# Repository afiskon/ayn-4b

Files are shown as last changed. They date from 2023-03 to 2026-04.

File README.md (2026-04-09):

# AYN/4B

Portable QRP CW Transceiver

* Covers 40, 30, 20 and 17 meters
* Classical single IF superheterodyne design
* Has just a few barely hearable (~S0) spurious signals
* Simple but effective AGC
* Supports RIT and XIT
* 10-30 WPM Elekey-B type keyer + straight key mode
* Keyer supports record and playback, programmable with paddles
* ~5W class D power amplifier
* Has a VCC indicator and a SWR meter
* PCB is designed to fit into Hammond 1590BB enclosure
* The project is 100% open-source

Links:
* Article (in Russian): https://eax.me/2023/2023-05-01-ayn-4b-transceiver.html
* Demo: https://www.youtube.com/watch?v=IM0qo4IA7QQ
* Fork by Kirill, R2AXZ with CMake support: https://github.com/r2axz/ayn-4b

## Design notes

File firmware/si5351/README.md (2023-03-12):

# stm32-si5351

HAL-based Si5351 driver for STM32.

Main respository: https://github.com/afiskon/stm32-si5351

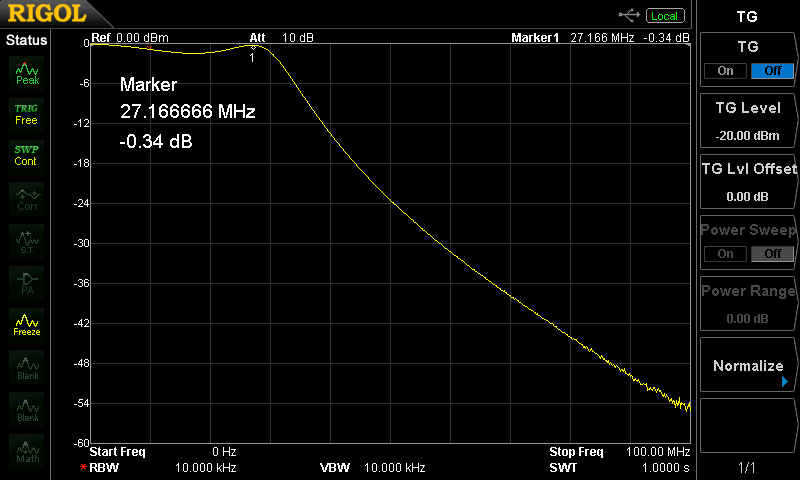
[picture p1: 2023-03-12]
images/lpfs/vfo-filter.png

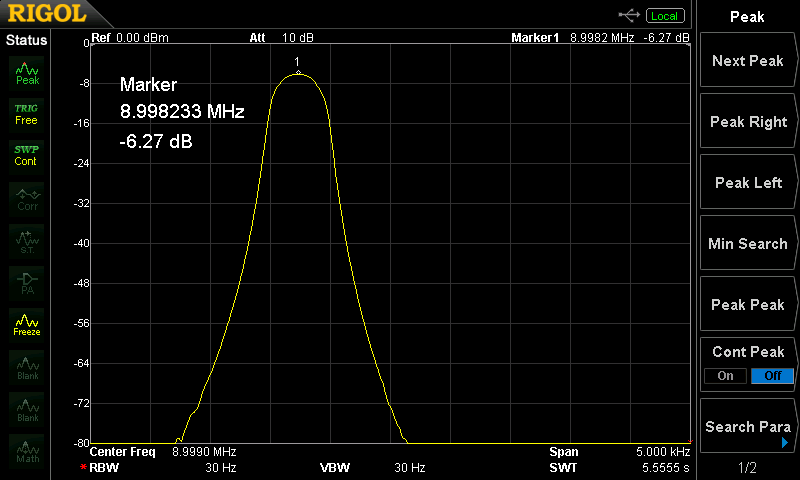
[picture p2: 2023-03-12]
images/xtal-filter/insertion-loss.png

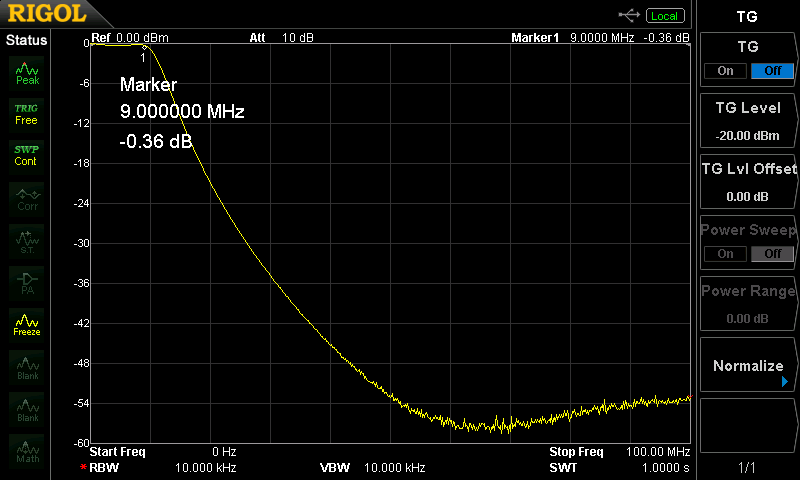
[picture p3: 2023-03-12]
images/lpfs/bfo-filter.png

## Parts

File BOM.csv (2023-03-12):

Reference | Quantity | Value | Footprint
C1 C93 C94 | 3 | 470p | Capacitor_SMD:C_0805_2012Metric_Pad1.15x1.40mm_HandSolder
C10 | 1 | 3.9p | Capacitor_SMD:C_0805_2012Metric_Pad1.15x1.40mm_HandSolder
C11 | 1 | 5.6p | Capacitor_SMD:C_0805_2012Metric_Pad1.15x1.40mm_HandSolder
C14 C95 C96 | 3 | 220p | Capacitor_SMD:C_0805_2012Metric_Pad1.15x1.40mm_HandSolder
C13 C15 C16 C17 | 4 | 330p | Capacitor_SMD:C_0805_2012Metric_Pad1.15x1.40mm_HandSolder
C19 | 1 | 33p | Capacitor_SMD:C_0805_2012Metric_Pad1.15x1.40mm_HandSolder
C3 C6 | 2 | 0.47u | Capacitor_SMD:C_0805_2012Metric_Pad1.15x1.40mm_HandSolder
C2 C4 C5 C7 C26 C27 C28 C29 C30 C31 C32 C34 C35 C36 C37 C38 C39 C40 C41 C42 C43 C45 C49 C50 C51 C53 C54 C55 C57 C81 C88 C89 C90 C91 C92 C97 C99 C102 C104 C105 | 40 | 0.1u | Capacitor_SMD:C_0805_2012Metric_Pad1.15x1.40mm_HandSolder
C46 C86 | 2 | 0.047u | Capacitor_SMD:C_0805_2012Metric_Pad1.15x1.40mm_HandSolder
C44 C47 C82 C83 C84 | 5 | 10u | Capacitor_SMD:CP_Elec_4x5.4
C48 | 1 | 2.2u | Capacitor_SMD:CP_Elec_4x5.4
C52 | 1 | 220u | Capacitor_SMD:CP_Elec_8x10.5
C60 C65 C70 C75 C80 C98 | 6 | 270p | Capacitor_SMD:C_0805_2012Metric_Pad1.15x1.40mm_HandSolder
C18 C20 C21 C22 C23 C24 C61 C64 C100 C101 | 10 | 150p | Capacitor_SMD:C_0805_2012Metric_Pad1.15x1.40mm_HandSolder
C62 C63 C67 C68 C72 C73 C77 C78 C103 | 9 | 1-30p | My_Library:C_Trim_THD_L7.0mm_W6.5mm_P5.00mm
C66 C69 | 2 | 100p | Capacitor_SMD:C_0805_2012Metric_Pad1.15x1.40mm_HandSolder
C71 C74 | 2 | 47p | Capacitor_SMD:C_0805_2012Metric_Pad1.15x1.40mm_HandSolder
C12 C25 C76 C79 | 4 | 68p | Capacitor_SMD:C_0805_2012Metric_Pad1.15x1.40mm_HandSolder
C8 | 1 | 15p | Capacitor_SMD:C_0805_2012Metric_Pad1.15x1.40mm_HandSolder
C33 C56 C58 C59 C85 | 5 | 0.01u | Capacitor_SMD:C_0805_2012Metric_Pad1.15x1.40mm_HandSolder
C87 | 1 | 22u | Capacitor_SMD:CP_Elec_5x5.4
C9 | 1 | 8p | Capacitor_SMD:C_0805_2012Metric_Pad1.15x1.40mm_HandSolder
D1 D2 D3 D6 D7 D8 D9 D10 D11 D12 D13 D15 D17 | 13 | 1N4148W | Diode_SMD:D_SOD-123
D14 | 1 | SS14 | Diode_SMD:D_SMA_Handsoldering
D16 | 1 | 1N4736A | Diode_THT:D_DO-41_SOD81_P2.54mm_Vertical_AnodeUp
D4 D5 | 2 | 1N34/D311 matched pair | Diode_THT:D_DO-41_SOD81_P2.54mm_Vertical_AnodeUp
K1 K2 K3 K4 K5 K6 K7 K8 K9 K10 K11 K12 | 12 | G6K-2F-Y (or: HFD4/12-S) | Relay_SMD:Relay_DPDT_Omron_G6K-2F-Y
Q1 Q2 Q5 Q6 Q8 Q9 Q10 Q11 Q13 Q14 Q15 Q16 Q17 Q18 | 14 | MMBT3904 | Package_TO_SOT_SMD:SOT-23
Q12 | 1 | BS170 | Package_TO_SOT_THT:TO-92_Inline
Q3 | 1 | MMBF170 | Package_TO_SOT_SMD:SOT-23
Q4 | 1 | MMBT3906 | Package_TO_SOT_SMD:SOT-23
Q7 | 1 | IRF510 | Package_TO_SOT_THT:TO-220-3_Vertical
R1 | 1 | 15K | Resistor_SMD:R_0805_2012Metric_Pad1.15x1.40mm_HandSolder
R11 | 1 | 220 | Resistor_SMD:R_0805_2012Metric_Pad1.15x1.40mm_HandSolder
R14 R21 R23 | 3 | 1.3K | Resistor_SMD:R_0805_2012Metric_Pad1.15x1.40mm_HandSolder
R15 R24 R26 | 3 | 68 | Resistor_SMD:R_0805_2012Metric_Pad1.15x1.40mm_HandSolder
R17 R28 R29 | 3 | 6.2 | Resistor_SMD:R_0805_2012Metric_Pad1.15x1.40mm_HandSolder
R2 R5 R6 R54 R66 R67 R68 R69 | 8 | 4.7K | Resistor_SMD:R_0805_2012Metric_Pad1.15x1.40mm_HandSolder
R3 | 1 | 2.7K | Resistor_SMD:R_0805_2012Metric_Pad1.15x1.40mm_HandSolder
R30 R31 | 2 | 150 | Resistor_SMD:R_0805_2012Metric_Pad1.15x1.40mm_HandSolder
R32 | 1 | 36 | Resistor_SMD:R_0805_2012Metric_Pad1.15x1.40mm_HandSolder
R33 R59 R60 R63 R64 | 5 | 100 | Resistor_SMD:R_0805_2012Metric_Pad1.15x1.40mm_HandSolder
R34 R53 | 2 | 2.2K | Resistor_SMD:R_0805_2012Metric_Pad1.15x1.40mm_HandSolder
R35 R40 R45 | 3 | 100K | Resistor_SMD:R_0805_2012Metric_Pad1.15x1.40mm_HandSolder
R13 R20 R22 R36 | 4 | 3.3K | Resistor_SMD:R_0805_2012Metric_Pad1.15x1.40mm_HandSolder
R37 | 1 | 47K | Resistor_SMD:R_0805_2012Metric_Pad1.15x1.40mm_HandSolder
R10 R16 R25 R27 R38 R48 R56 R57 | 8 | 1K | Resistor_SMD:R_0805_2012Metric_Pad1.15x1.40mm_HandSolder
R39 | 1 | 51 | Resistor_SMD:R_0805_2012Metric_Pad1.15x1.40mm_HandSolder
R4 R9 R41 R42 R43 R44 | 6 | 1.8K | Resistor_SMD:R_0805_2012Metric_Pad1.15x1.40mm_HandSolder
R12 R18 R19 R46 R49 | 5 | 22 | Resistor_SMD:R_0805_2012Metric_Pad1.15x1.40mm_HandSolder
R50 | 1 | 10 | Resistor_SMD:R_0805_2012Metric_Pad1.15x1.40mm_HandSolder
R51 | 1 | 1Meg | Resistor_SMD:R_0805_2012Metric_Pad1.15x1.40mm_HandSolder
R52 R61 R65 | 3 | 680 | Resistor_SMD:R_0805_2012Metric_Pad1.15x1.40mm_HandSolder
R47 R55 | 2 | 10K | Resistor_SMD:R_0805_2012Metric_Pad1.15x1.40mm_HandSolder
R58 R62 | 2 | 300 | Resistor_SMD:R_0805_2012Metric_Pad1.15x1.40mm_HandSolder
RV1 RV2 RV3 RV4 | 4 | 10K | Potentiometer_THT:Potentiometer_Bourns_3296W_Vertical
U1 | 1 | L7805 | Package_TO_SOT_THT:TO-220-3_Vertical
U10 | 1 | LM386 | Package_SO:SO-8_5.3x6.2mm_P1.27mm
U11 | 1 | L7805 | Package_TO_SOT_SMD:TO-263-2
U2 | 1 | 24LC64 | Package_SO:SO-8_5.3x6.2mm_P1.27mm
U3 U4 | 2 | ADE-6 (or: ADE-1/ADE-1L/ADE-2) | RF_Mini-Circuits:Mini-Circuits_CD542_LandPatternPL-052
U5 | 1 | NE5532 | Package_SO:SOIC-8_5.23x5.23mm_P1.27mm
Y1 Y2 Y3 Y4 Y5 Y6 | 6 | 9 Mhz, see notes
T1 T2 T3 T12 L9 | 5 | FT37-43
T4 T5 T6 T7 T8 T9 T10 T11 L3 L4 L5 L6 L7 L8 L10 L11 | 16 | T37-6
J8 J9 J11 J12 | 1 | BN61-202
L1 L2 | 2 | 1000u
L12 | 1 | 18u
J2 | 1 | Si5351 Module
J3 J4 | 1 | Blue Pill

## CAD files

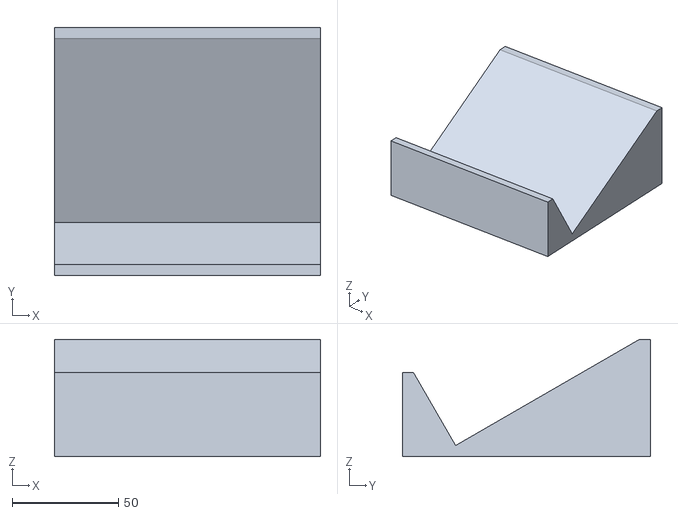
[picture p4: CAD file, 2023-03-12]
stl-files/desktop-stand.stl
125.0 x 116.6 x 55.0

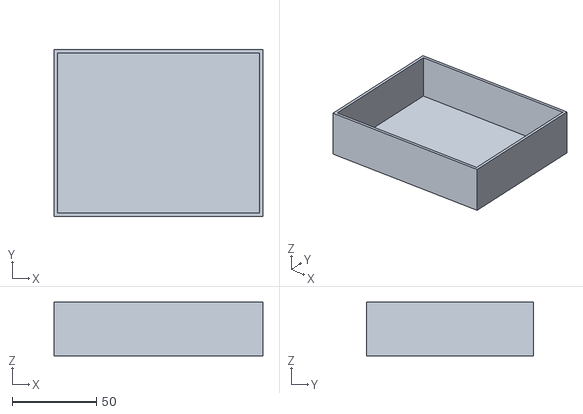
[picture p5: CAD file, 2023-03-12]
stl-files/dust-cover.stl
124.0 x 99.0 x 32.0

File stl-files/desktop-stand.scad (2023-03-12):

X = 125;
Y = 100;
Z = 40;
T = 5;
A = 30;
eps = 0.01;

by = T*2 + Y*sin(90-A) + Z*sin(A);
bx = X;
bz = T + Y*sin(A);


difference(){
    cube([bx, by, bz], center = true);

    translate([0,0, Z/2])
        rotate([A, 0, 0])
            cube([X+eps, Y, Z], center = true);
    
    translate([0, -Z, Z*0.8])
        cube([X+eps, Z, Z], center = true);
}

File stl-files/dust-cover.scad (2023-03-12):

T = 2;
X = 120;
Y = 95;
Z = 30;
eps = 0.01;

difference() {
    cube([X+2*T, Y+2*T, Z+T], center = true);
    translate([0, 0, T/2 + eps])
        cube([X, Y, Z], center = true);
}

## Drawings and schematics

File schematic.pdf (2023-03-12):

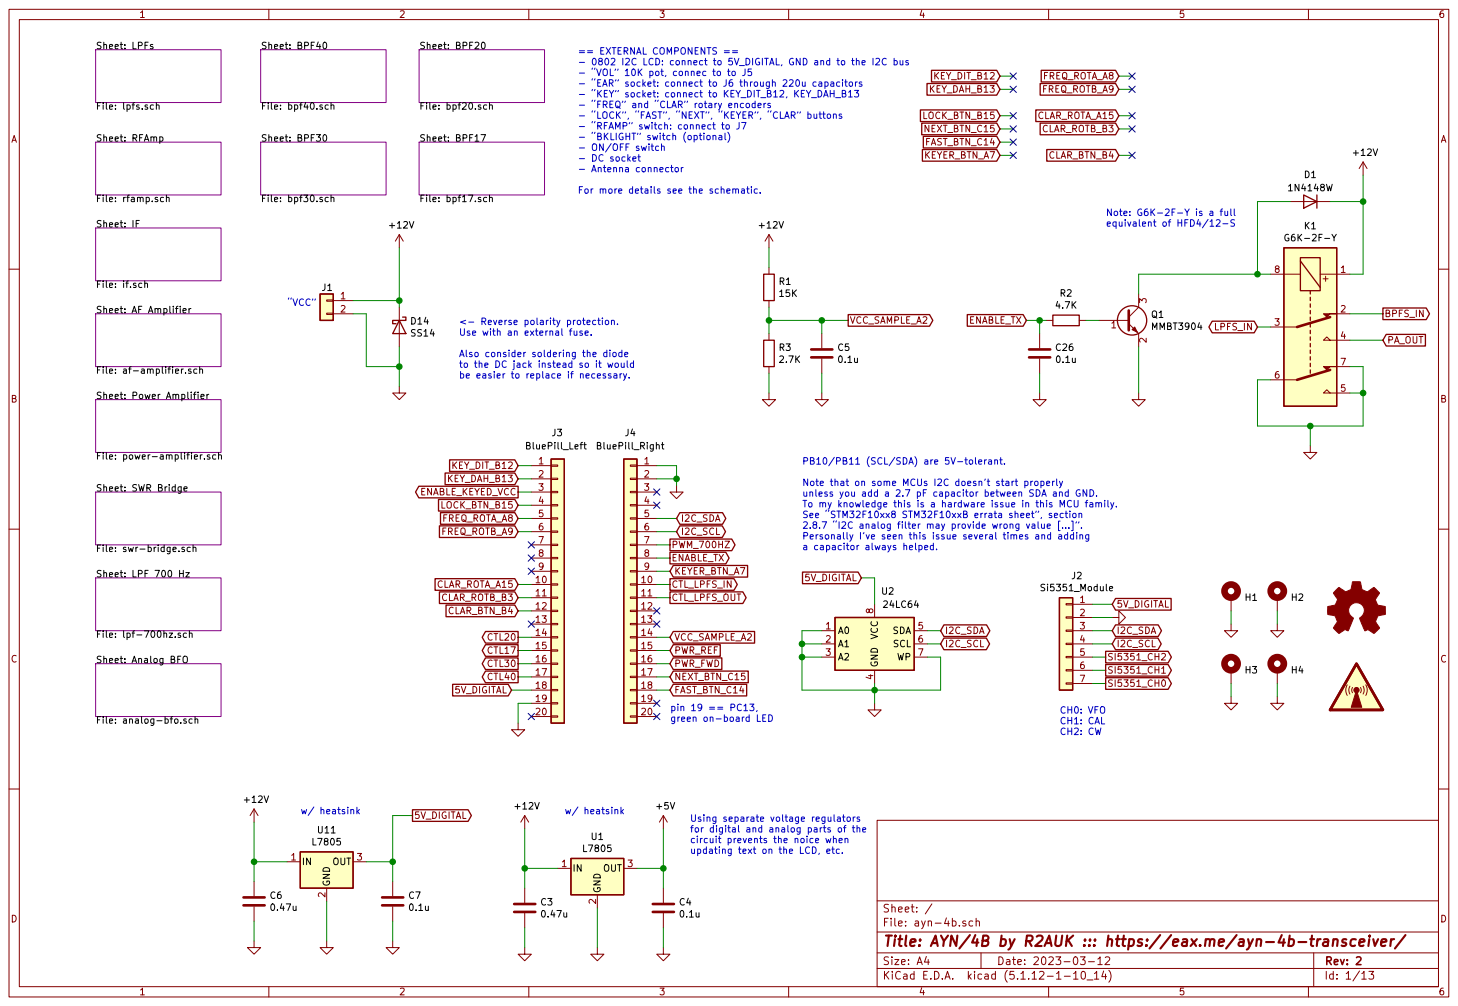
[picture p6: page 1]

- DC socket - Antenna connector For more details see the schematic. pin 19 == PC13,

File: if.sch Sheet: RFAmp
File: analog-bfo.sch Sheet: LPF 700 Hz File: lpf-700hz.sch Sheet: IF

== EXTERNAL COMPONENTS ==
- 0802 I2C LCD: connect to 5V_DIGITAL, GND and to the I2C bus
- VOL 10K pot, connec to to J5
- EAR socket: connect to J6 through 220u capacitors
- KEY socket: connect to KEY_DIT_B12, KEY_DAH_B13
- FREQ and CLAR rotary encoders
- LOCK, FAST, NEXT, KEYER, CLAR buttons
- RFAMP switch: connect to J7
- BKLIGHT switch (optional)
- ON/OFF switch

<- Reverse polarity protection. Use with an external fuse. Also consider soldering the diode

to the DC jack instead so it would
be easier to replace if necessary.

File: af-amplifier.sch

File: power-amplifier.sch

Note that on some MCUs I2C doesnt start properly
unless you add a 2.7 pF capacitor between SDA and GND.
To my knowledge this is a hardware issue in this MCU family. See STM32F10xx8 STM32F10xxB errata sheet, section

2.8.7 I2C analog filter may provide wrong value [].
Personally Ive seen this issue several times and adding
a capacitor always helped.

File: swr-bridge.sch

4 SDA 5 SCL 6 WP 7 VCC

Using separate voltage regulators
for digital and analog parts of the
circuit prevents the noice when
updating text on the LCD, etc.

File: ayn-4b.sch Sheet: /
Id: 1/13 Title: AYN/4B by R2AUK ::: https://eax.me/ayn-4b-transceiver/

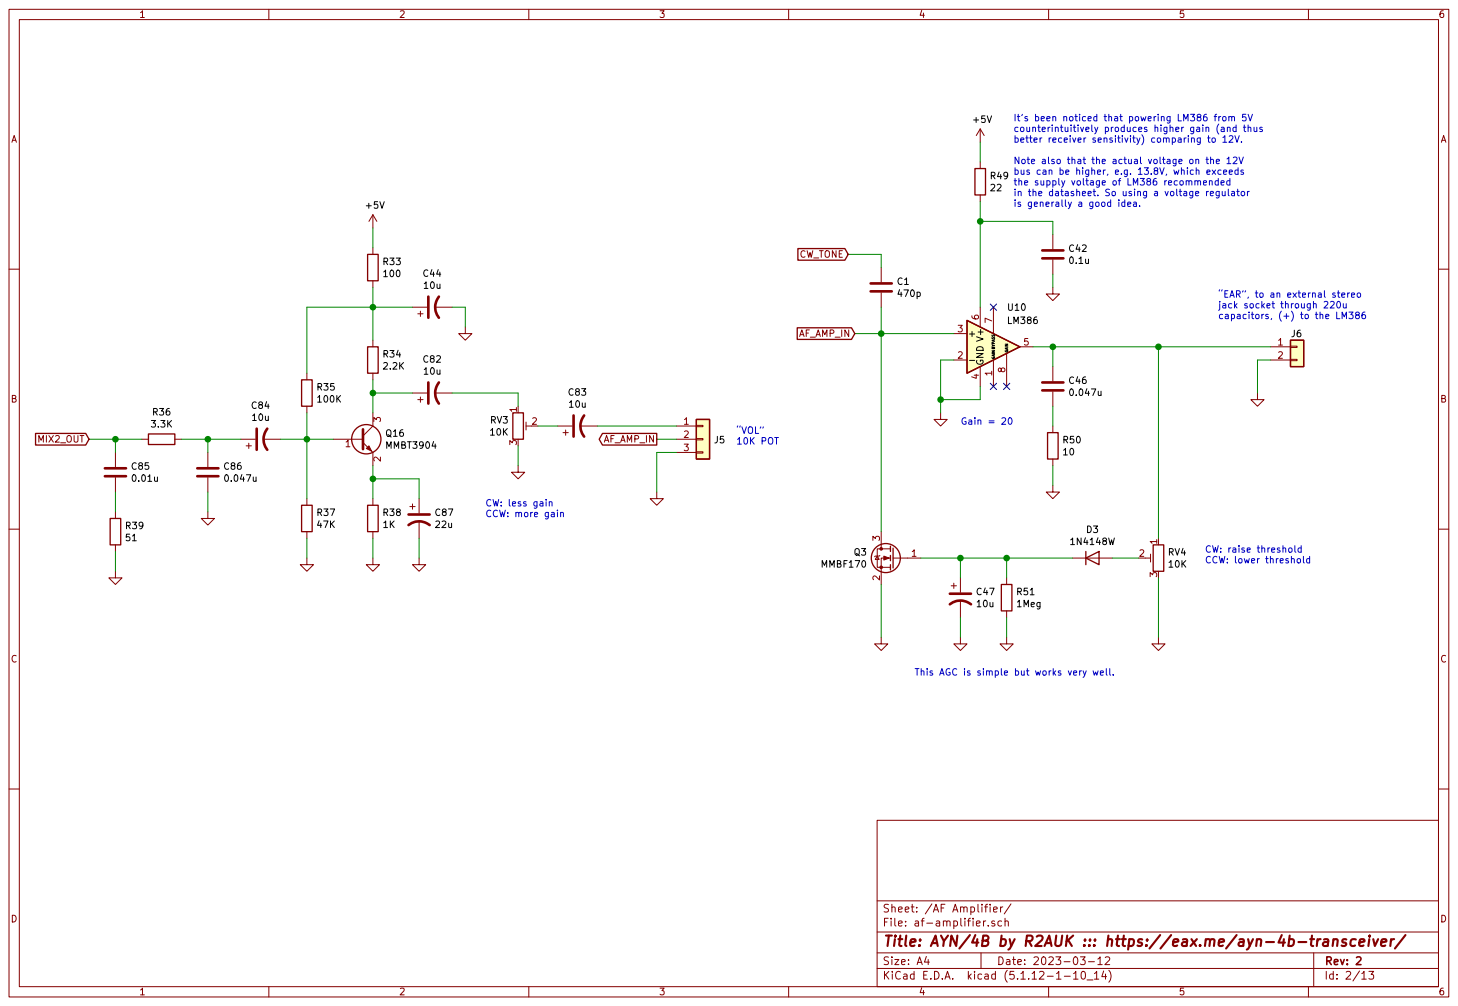
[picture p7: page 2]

Its been noticed that powering LM386 from 5V
counterintuitively produces higher gain (and thus
better receiver sensitivity) comparing to 12V.

Note also that the actual voltage on the 12V
bus can be higher, e.g. 13.8V, which exceeds
the supply voltage of LM386 recommended
in the datasheet. So using a voltage regulator

This AGC is simple but works very well. Gain = 20

Sheet: /AF Amplifier/
File: af-amplifier.sch
Id: 2/13 Title: AYN/4B by R2AUK ::: https://eax.me/ayn-4b-transceiver/

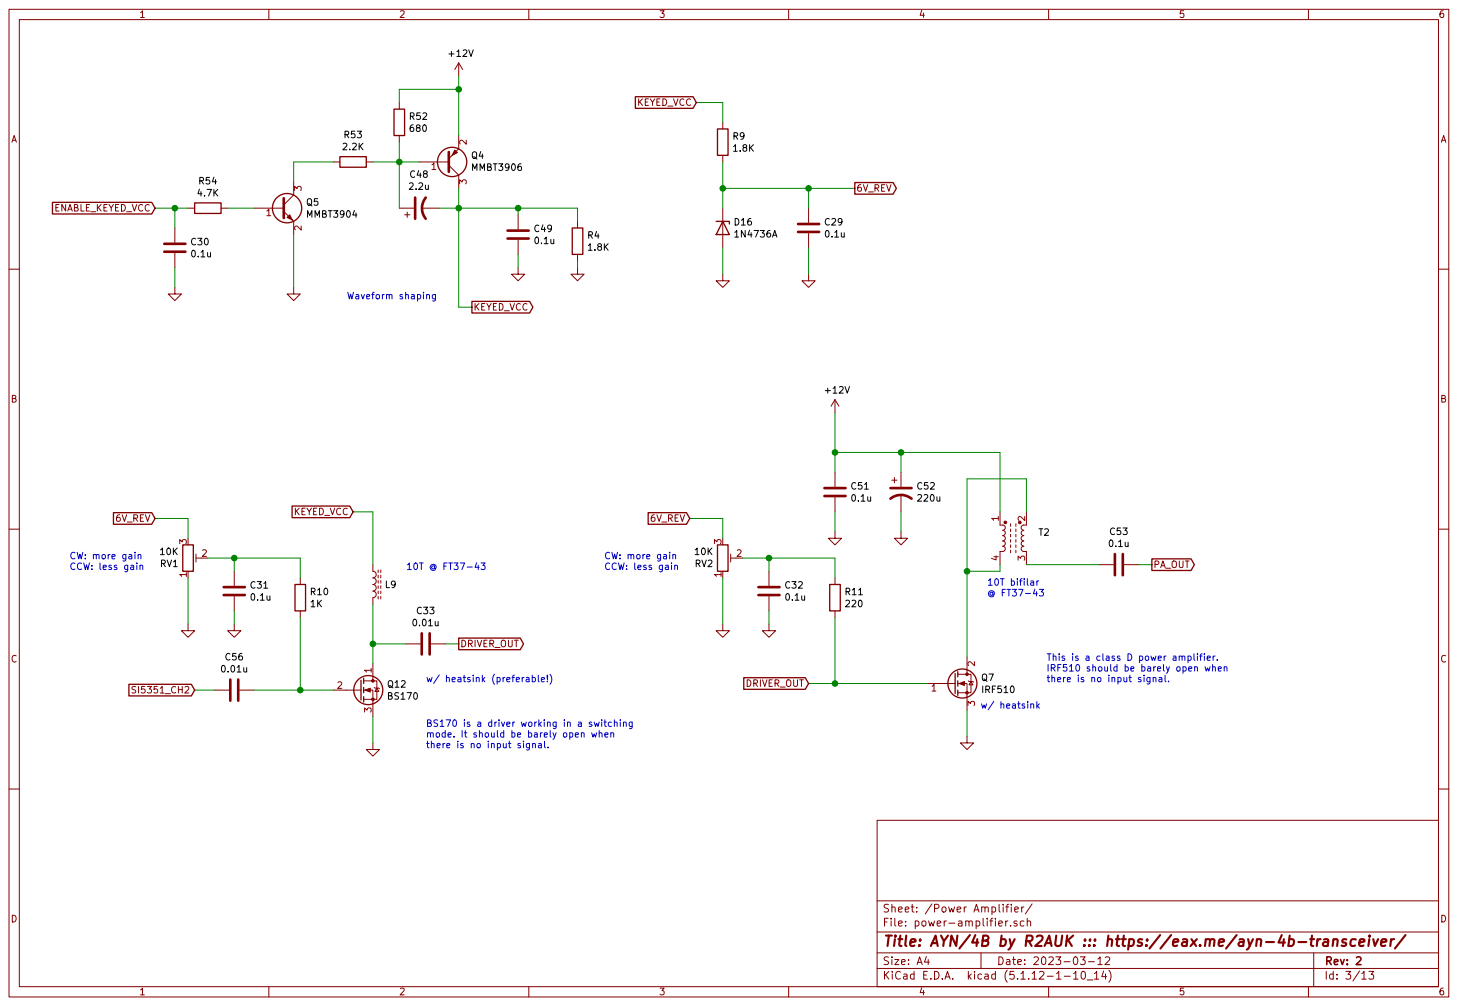
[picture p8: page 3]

IRF510 should be barely open when
there is no input signal.

BS170 is a driver working in a switching
mode. It should be barely open when

File: power-amplifier.sch
Id: 3/13 Title: AYN/4B by R2AUK ::: https://eax.me/ayn-4b-transceiver/

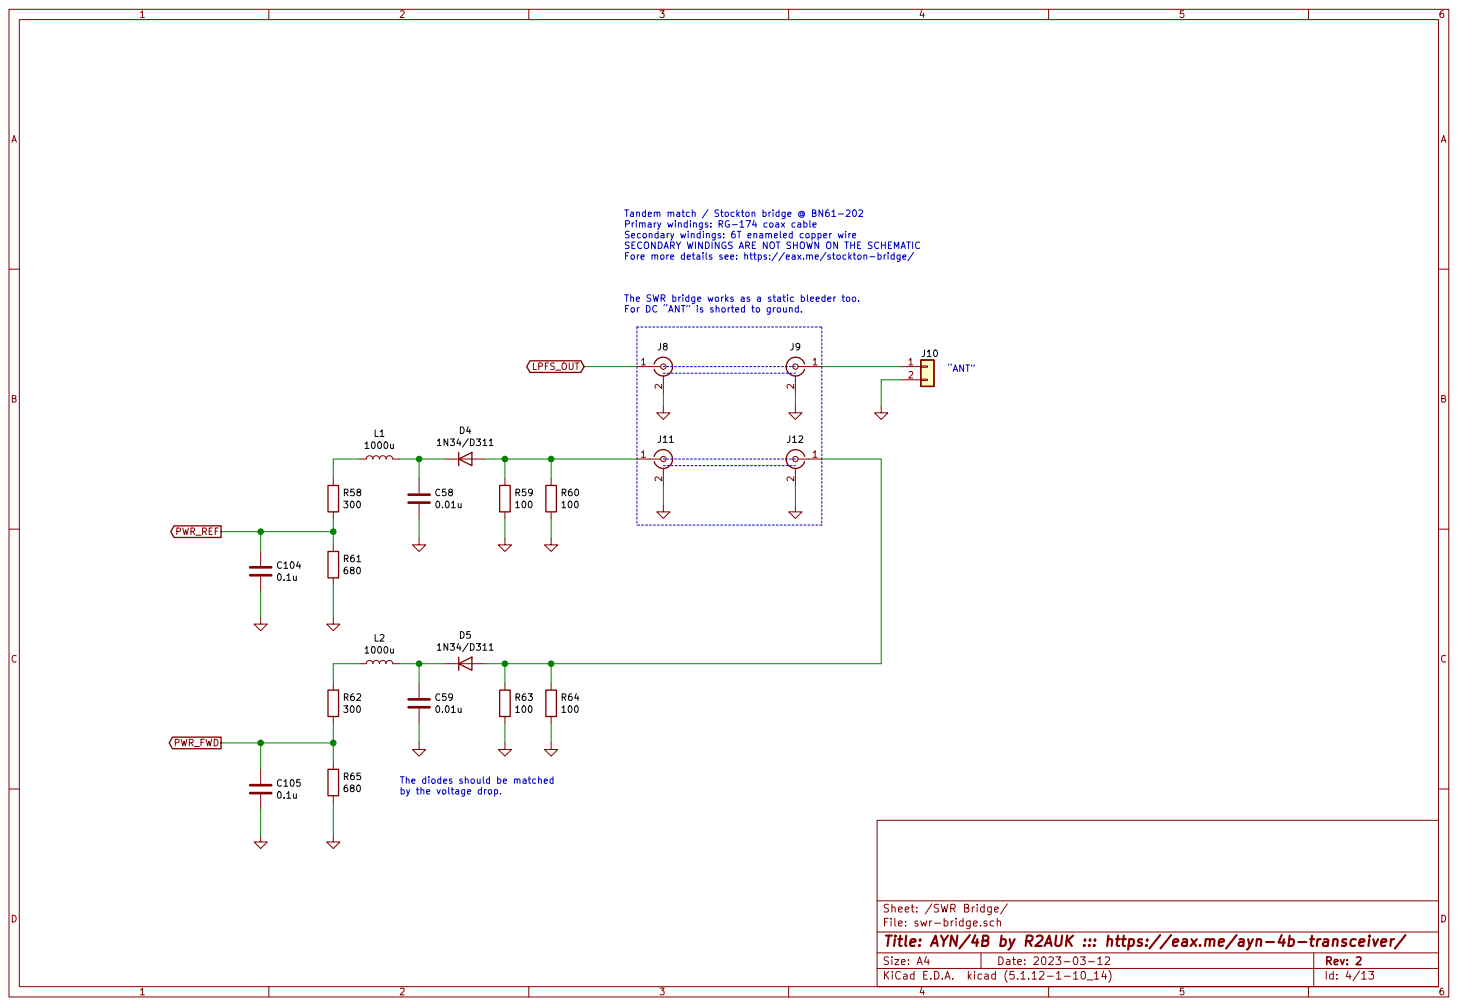
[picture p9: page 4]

Tandem match / Stockton bridge @ BN61-202
Primary windings: RG-174 coax cable
Secondary windings: 6T enameled copper wire SECONDARY WINDINGS ARE NOT SHOWN ON THE SCHEMATIC

Fore more details see: https://eax.me/stockton-bridge/

The SWR bridge works as a static bleeder too.

For DC ANT is shorted to ground. The diodes should be matched

Sheet: /SWR Bridge/
File: swr-bridge.sch
Id: 4/13 Title: AYN/4B by R2AUK ::: https://eax.me/ayn-4b-transceiver/

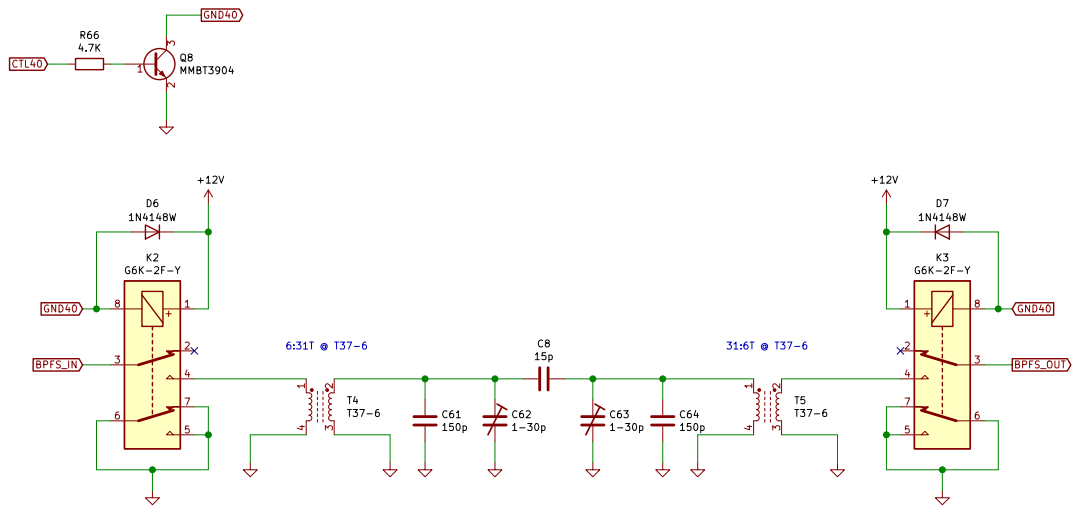
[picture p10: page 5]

Id: 5/13 Title: AYN/4B by R2AUK ::: https://eax.me/ayn-4b-transceiver/

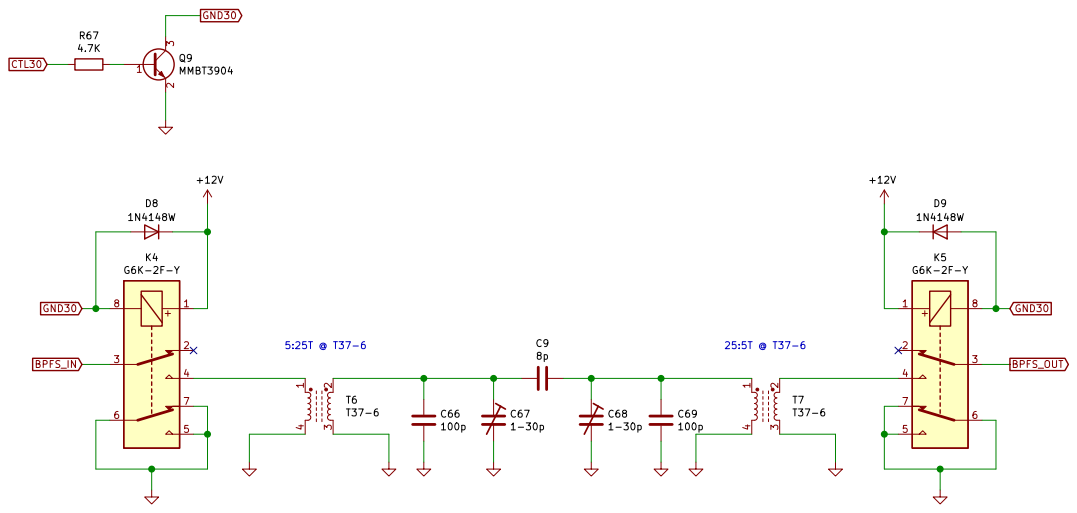
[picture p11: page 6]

Id: 6/13 Title: AYN/4B by R2AUK ::: https://eax.me/ayn-4b-transceiver/

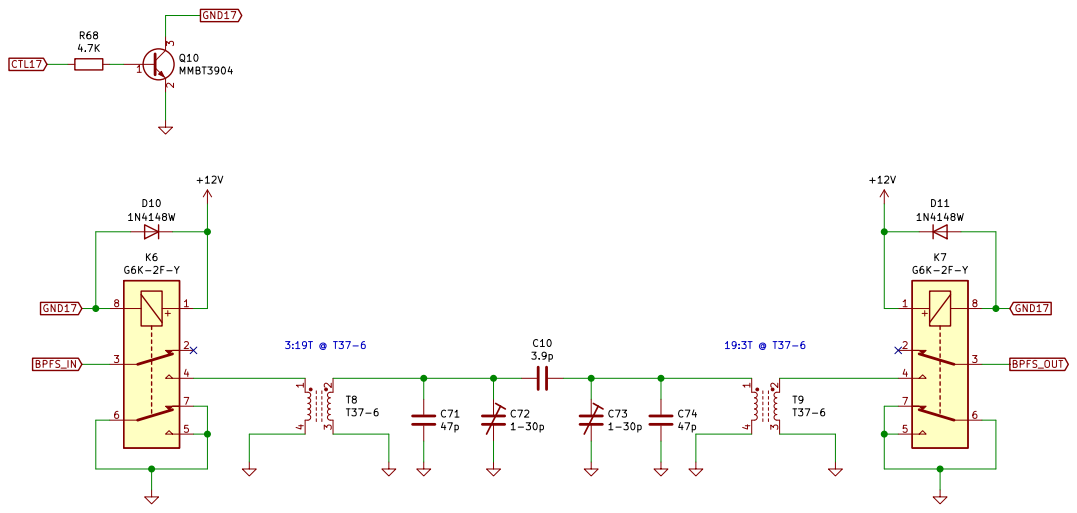
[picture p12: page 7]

Id: 7/13 Title: AYN/4B by R2AUK ::: https://eax.me/ayn-4b-transceiver/

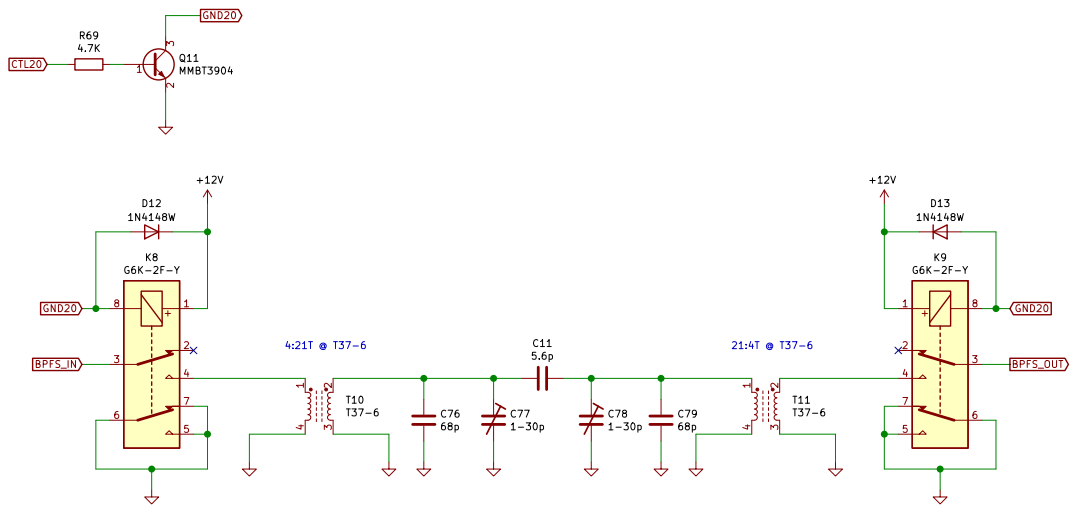
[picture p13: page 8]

Id: 8/13 Title: AYN/4B by R2AUK ::: https://eax.me/ayn-4b-transceiver/

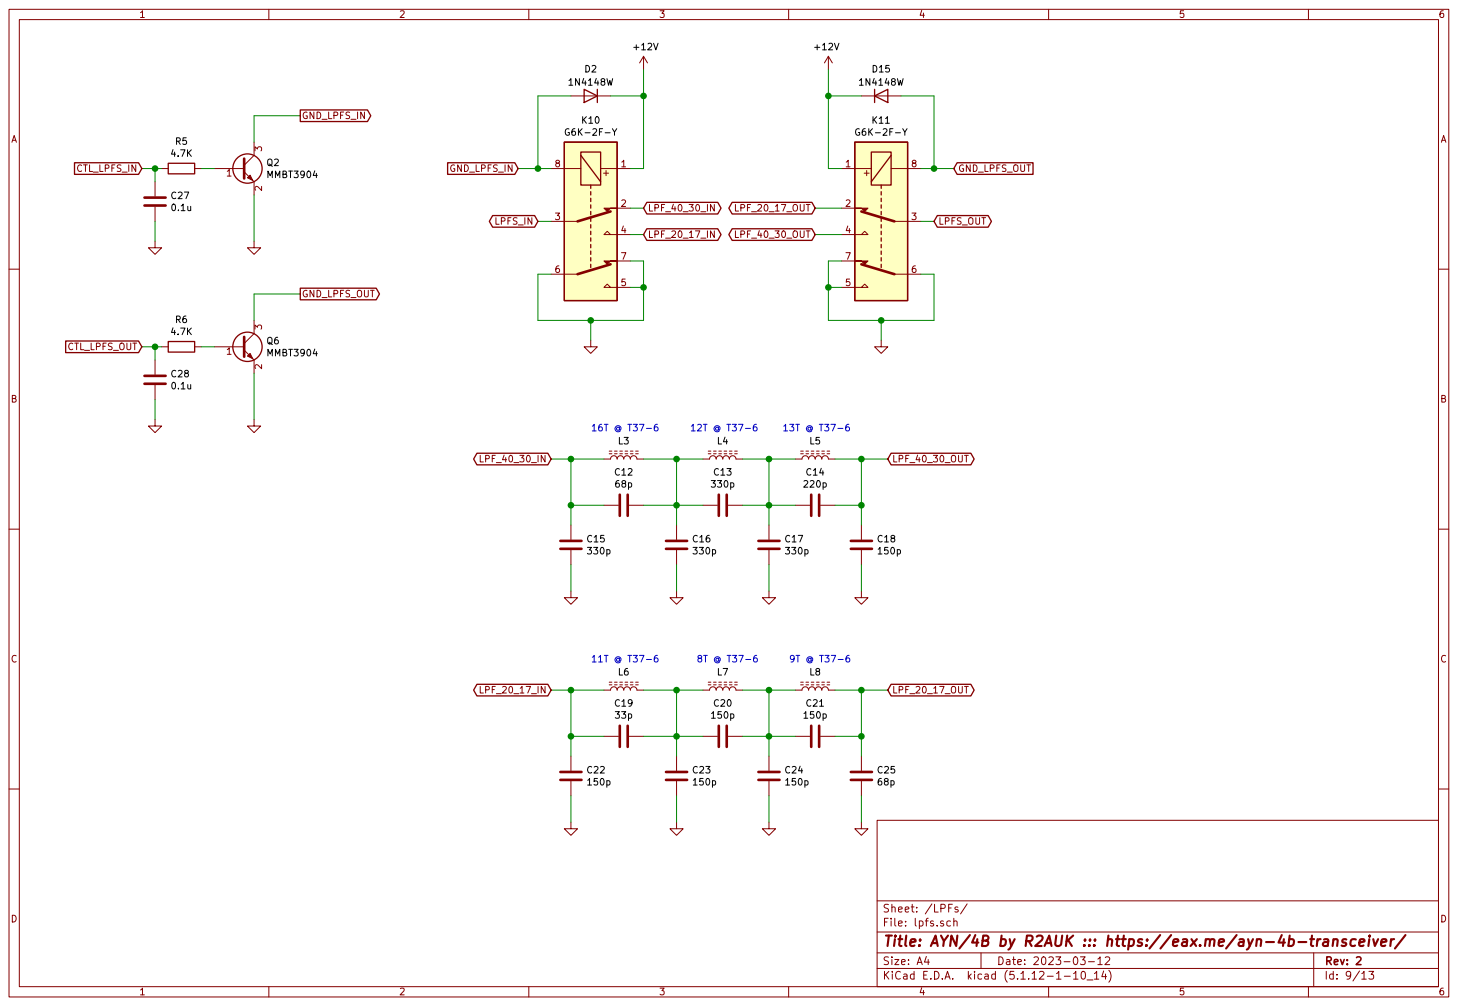
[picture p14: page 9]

File: lpfs.sch Sheet: /LPFs/
Id: 9/13 Title: AYN/4B by R2AUK ::: https://eax.me/ayn-4b-transceiver/

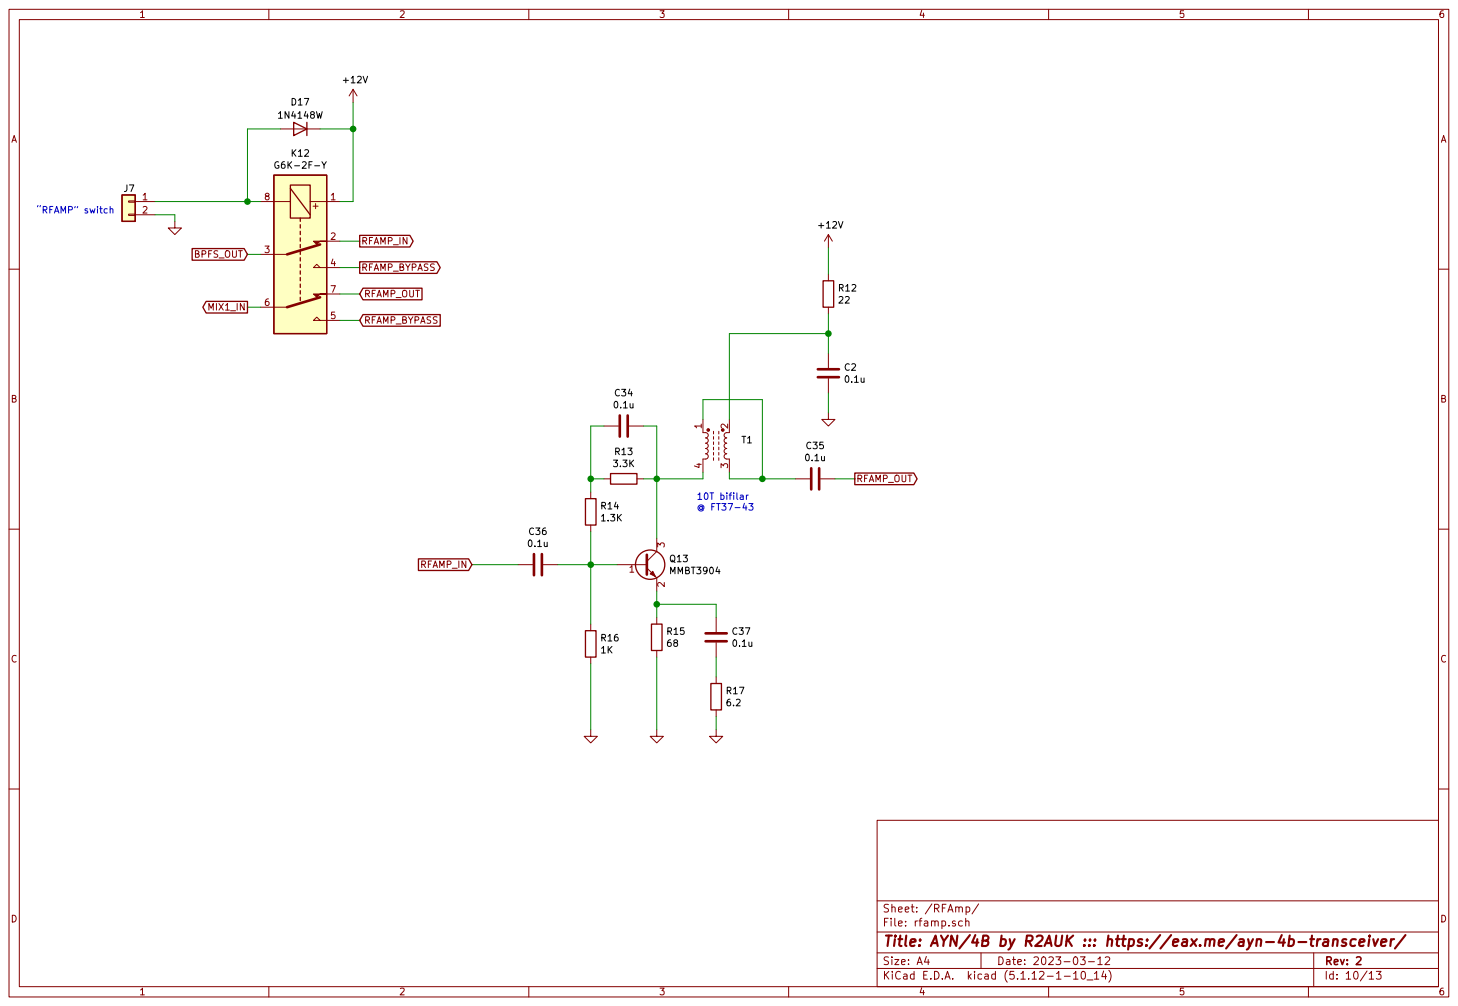
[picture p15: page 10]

Sheet: /RFAmp/
File: rfamp.sch
Id: 10/13 Title: AYN/4B by R2AUK ::: https://eax.me/ayn-4b-transceiver/

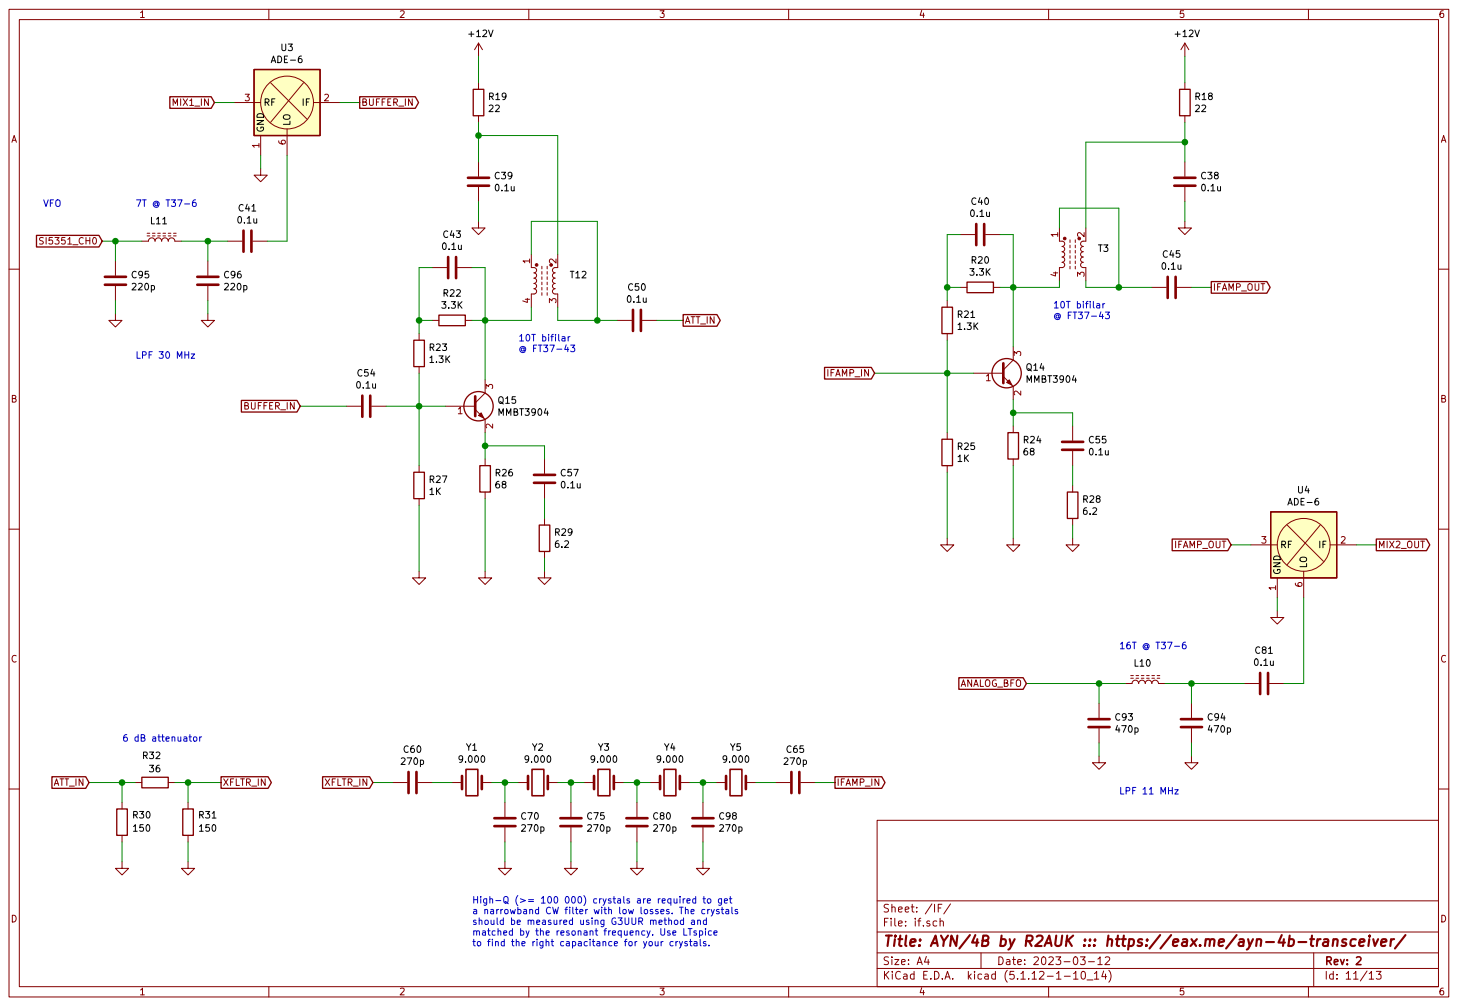
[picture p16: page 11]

Id: 11/13 Title: AYN/4B by R2AUK ::: https://eax.me/ayn-4b-transceiver/ File: if.sch Sheet: /IF/ GND

16T @ T37-6 High-Q (>= 100 000) crystals are required to get

a narrowband CW filter with low losses. The crystals
should be measured using G3UUR method and
matched by the resonant frequency. Use LTspice

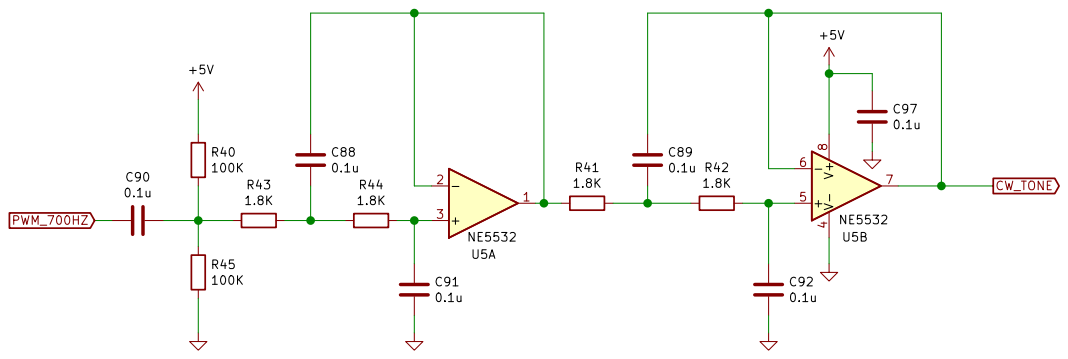
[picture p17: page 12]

File: lpf-700hz.sch Sheet: /LPF 700 Hz/
Id: 12/13 Title: AYN/4B by R2AUK ::: https://eax.me/ayn-4b-transceiver/


The secret of a superheterodyne receiver free of spurious
signals is a clean BFO. The signal of Si5351 is way too dirty
and cant be used as a BFO. Trust me, Ive tried many times.

The oscillator should be tuned to: (crystal filter center frequency) - 700 Hz

Example: Filter CF = 8.998.280 Hz Osc. Freq = 8.997.580 Hz

The expected output power to 50 Ohms is about
4 dBm on the main frequency (probably, mismatched).

This is not exactly 7 dBm typically required for a double
balanced diode ring mixer, but quite enought for ADE-6, see the datasheet. Some experimentation may be required.
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


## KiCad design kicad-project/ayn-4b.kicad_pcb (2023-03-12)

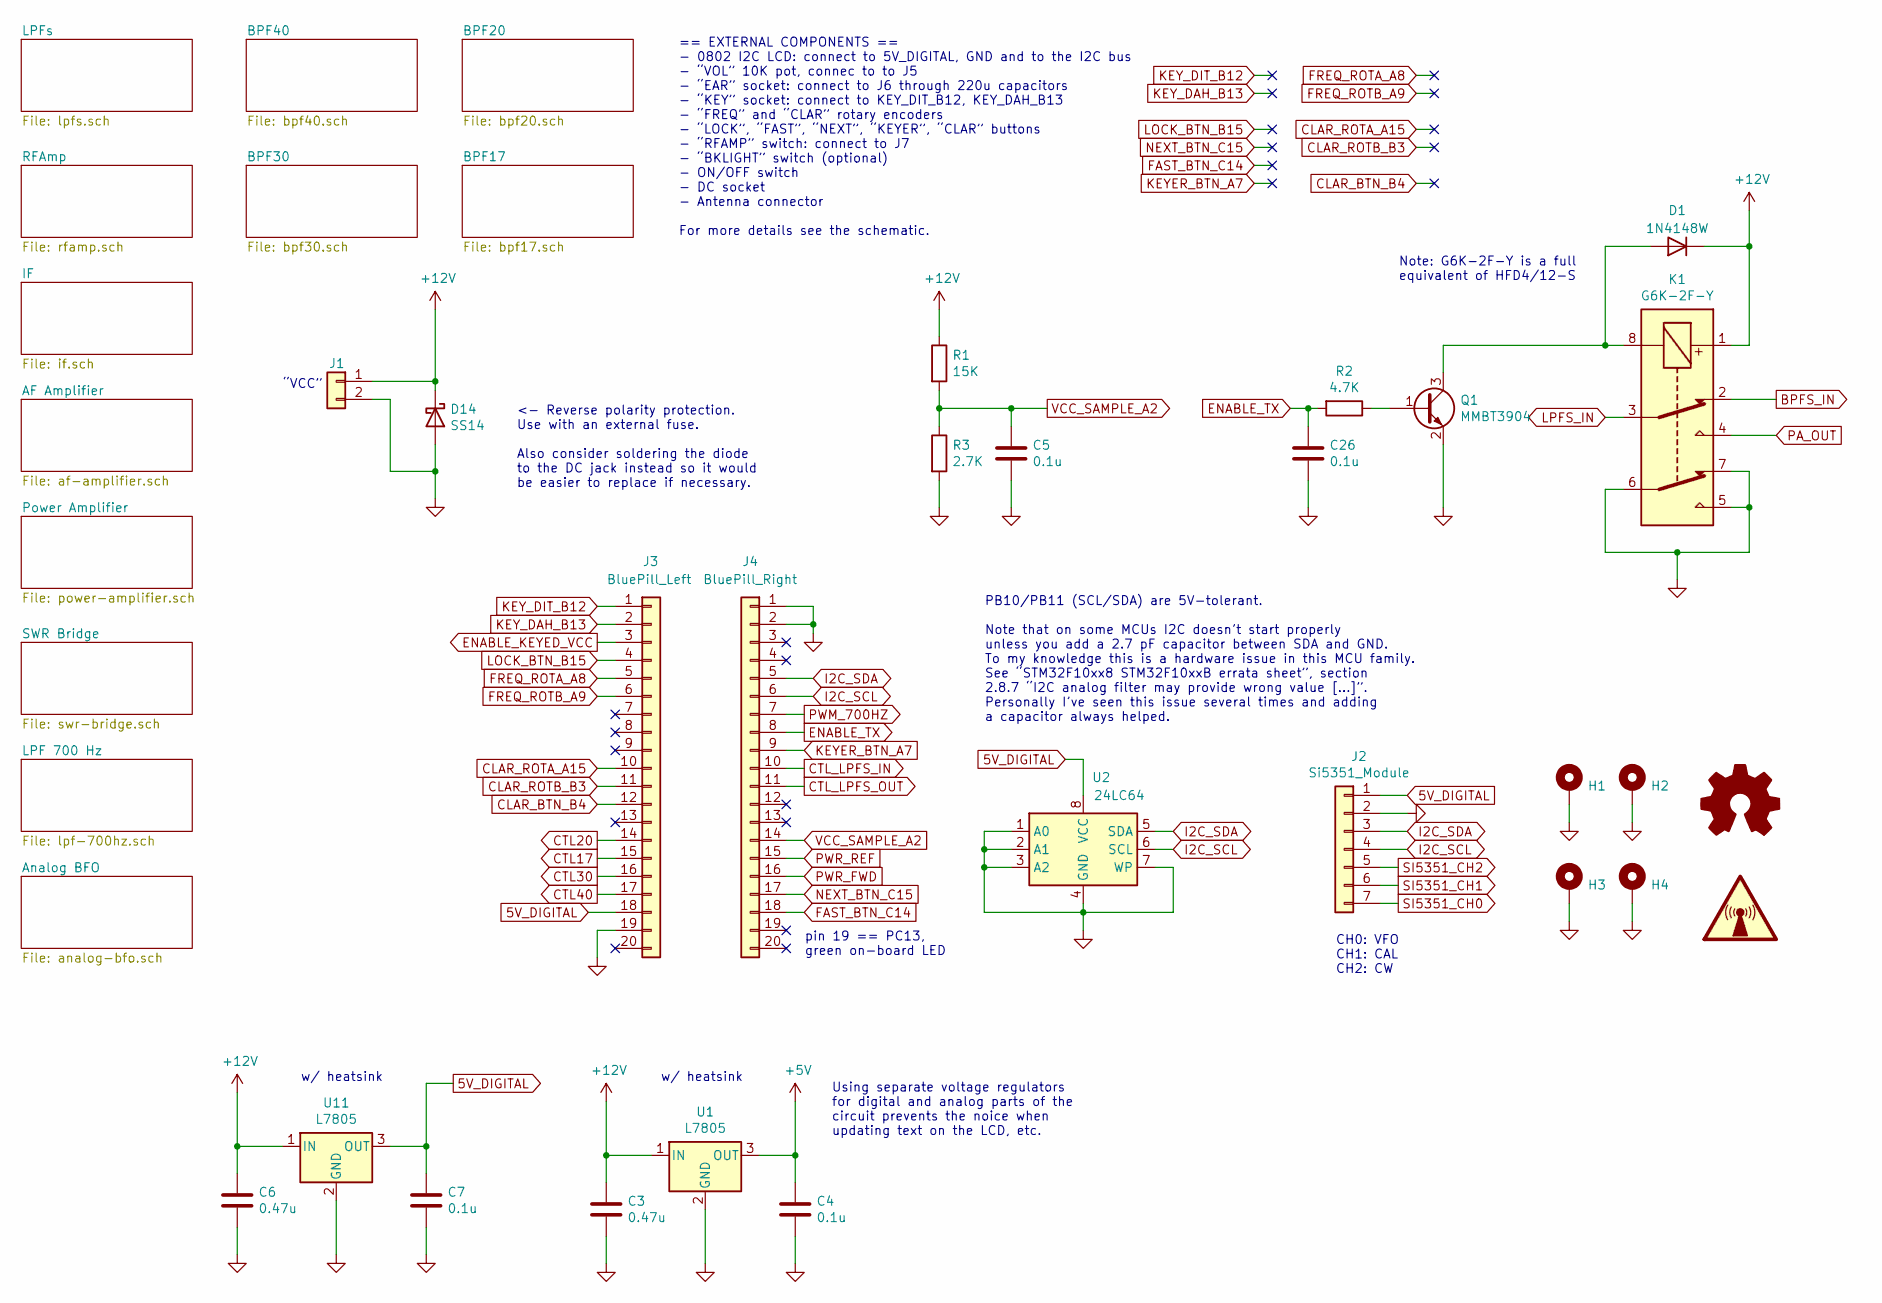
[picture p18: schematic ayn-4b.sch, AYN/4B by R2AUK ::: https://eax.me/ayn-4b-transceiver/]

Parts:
C3, C6: 0.47u; C_0805_2012Metric_Pad1.15x1.40mm_HandSolder
C4, C5, C7, C26: 0.1u; C_0805_2012Metric_Pad1.15x1.40mm_HandSolder
D1: 1N4148W; D_SOD-123
D14: SS14; D_SMA_Handsoldering
H1, H2, H3, H4: MountingHole_Pad; MountingHole_M3_Pad_Large
J1: Conn_01x02; PinSocket_1x02_P2.54mm_Vertical
J2: Si5351_Module; PinSocket_1x07_P2.54mm_Vertical
J3: BluePill_Left; PinSocket_1x20_P2.54mm_Vertical
J4: BluePill_Right; PinSocket_1x20_P2.54mm_Vertical
K1: G6K-2F-Y; Relay_DPDT_Omron_G6K-2F-Y
Q1: MMBT3904; SOT-23
R1: 15K; R_0805_2012Metric_Pad1.15x1.40mm_HandSolder
R2: 4.7K; R_0805_2012Metric_Pad1.15x1.40mm_HandSolder
R3: 2.7K; R_0805_2012Metric_Pad1.15x1.40mm_HandSolder
SYM1: Logo_Open_Hardware_Small; OSHW-Logo2_14.6x12mm_SilkScreen
SYM2: SYM_Radio_Waves_Large; KiCad-Logo_5mm_SilkScreen
U1: L7805; TO-220-3_Vertical
U2: 24LC64; SO-8_5.3x6.2mm_P1.27mm
U11: L7805; TO-263-2

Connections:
5V_DIGITAL: C7.1, J2.1, J3.18, U2.8 (VCC), U11.3 (OUT)
+5V: C4.1, U1.3 (OUT); also elsewhere on the board
+12V: C3.1, C6.1, D1.1 (K), D14.1 (K), J1.1, K1.1, R1.1, U1.1 (IN), U11.1 (IN); also elsewhere on the board
BPFS_IN: K1.2; also elsewhere on the board
CLAR_BTN_B4: J3.12
CLAR_ROTA_A15: J3.10
CLAR_ROTB_B3: J3.11
CTL17: J3.15; also elsewhere on the board
CTL20: J3.14; also elsewhere on the board
CTL30: J3.16; also elsewhere on the board
CTL40: J3.17; also elsewhere on the board
CTL_LPFS_IN: J4.10; also elsewhere on the board
CTL_LPFS_OUT: J4.11; also elsewhere on the board
ENABLE_KEYED_VCC: J3.3; also elsewhere on the board
ENABLE_TX: C26.1, J4.8, R2.2
FAST_BTN_C14: J4.18
FREQ_ROTA_A8: J3.5
FREQ_ROTB_A9: J3.6
GND: C3.2, C4.2, C5.2, C6.2, C7.2, C26.2, D14.2 (A), H1.1, H2.1, H3.1, H4.1, J1.2, J2.2, J3.19, J4.1, J4.2, K1.5, K1.6, K1.7, Q1.2 (E), R3.2, U1.2 (GND), U2.1 (A0), U2.2 (A1), U2.3 (A2), U2.4 (GND), U2.7 (WP), U11.2 (GND); also elsewhere on the board
I2C_SCL: J2.4, J4.6, U2.6 (SCL)
I2C_SDA: J2.3, J4.5, U2.5 (SDA)
KEYER_BTN_A7: J4.9
KEY_DAH_B13: J3.2
KEY_DIT_B12: J3.1
LOCK_BTN_B15: J3.4
LPFS_IN: K1.3; also elsewhere on the board
NEXT_BTN_C15: J4.17
unnamed: D1.2 (A), K1.8, Q1.3 (C)
unnamed: Q1.1 (B), R2.1
PA_OUT: K1.4; also elsewhere on the board
PWM_700HZ: J4.7; also elsewhere on the board
PWR_FWD: J4.16; also elsewhere on the board
PWR_REF: J4.15; also elsewhere on the board
SI5351_CH0: J2.7; also elsewhere on the board
SI5351_CH1: J2.6
SI5351_CH2: J2.5; also elsewhere on the board
VCC_SAMPLE_A2: C5.1, J4.14, R1.2, R3.1

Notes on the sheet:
CH0: VFO CH1: CAL CH2: CW
== EXTERNAL COMPONENTS == - 0802 I2C LCD: connect to 5V_DIGITAL, GND and to the I2C bus - “VOL” 10K pot, connec to to J5 - “EAR” socket: connect to J6 through 220u capacitors - “KEY” socket: connect to KEY_DIT_B12, KEY_DAH_B13 - “FREQ” and “CLAR” rotary encoders - “LOCK”, “FAST”, “NEXT”, “KEYER”, “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
w/ heatsink
Note: G6K-2F-Y is a full equivalent of HFD4/12-S
<- Reverse polarity protection. Use with an external fuse. Also consider soldering the diode to the DC jack instead so it would be easier to replace if necessary.
Using separate voltage regulators for digital and analog parts of the circuit prevents the noice when updating text on the LCD, etc.
“VCC”
PB10/PB11 (SCL/SDA) are 5V-tolerant. Note that on some MCUs I2C doesn’t start properly unless you add a 2.7 pF capacitor between SDA and GND. To my knowledge this is a hardware issue in this MCU family. See “STM32F10xx8 STM32F10xxB errata sheet”, section 2.8.7 “I2C analog filter may provide wrong v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
pin 19 == PC13, green on-board LED

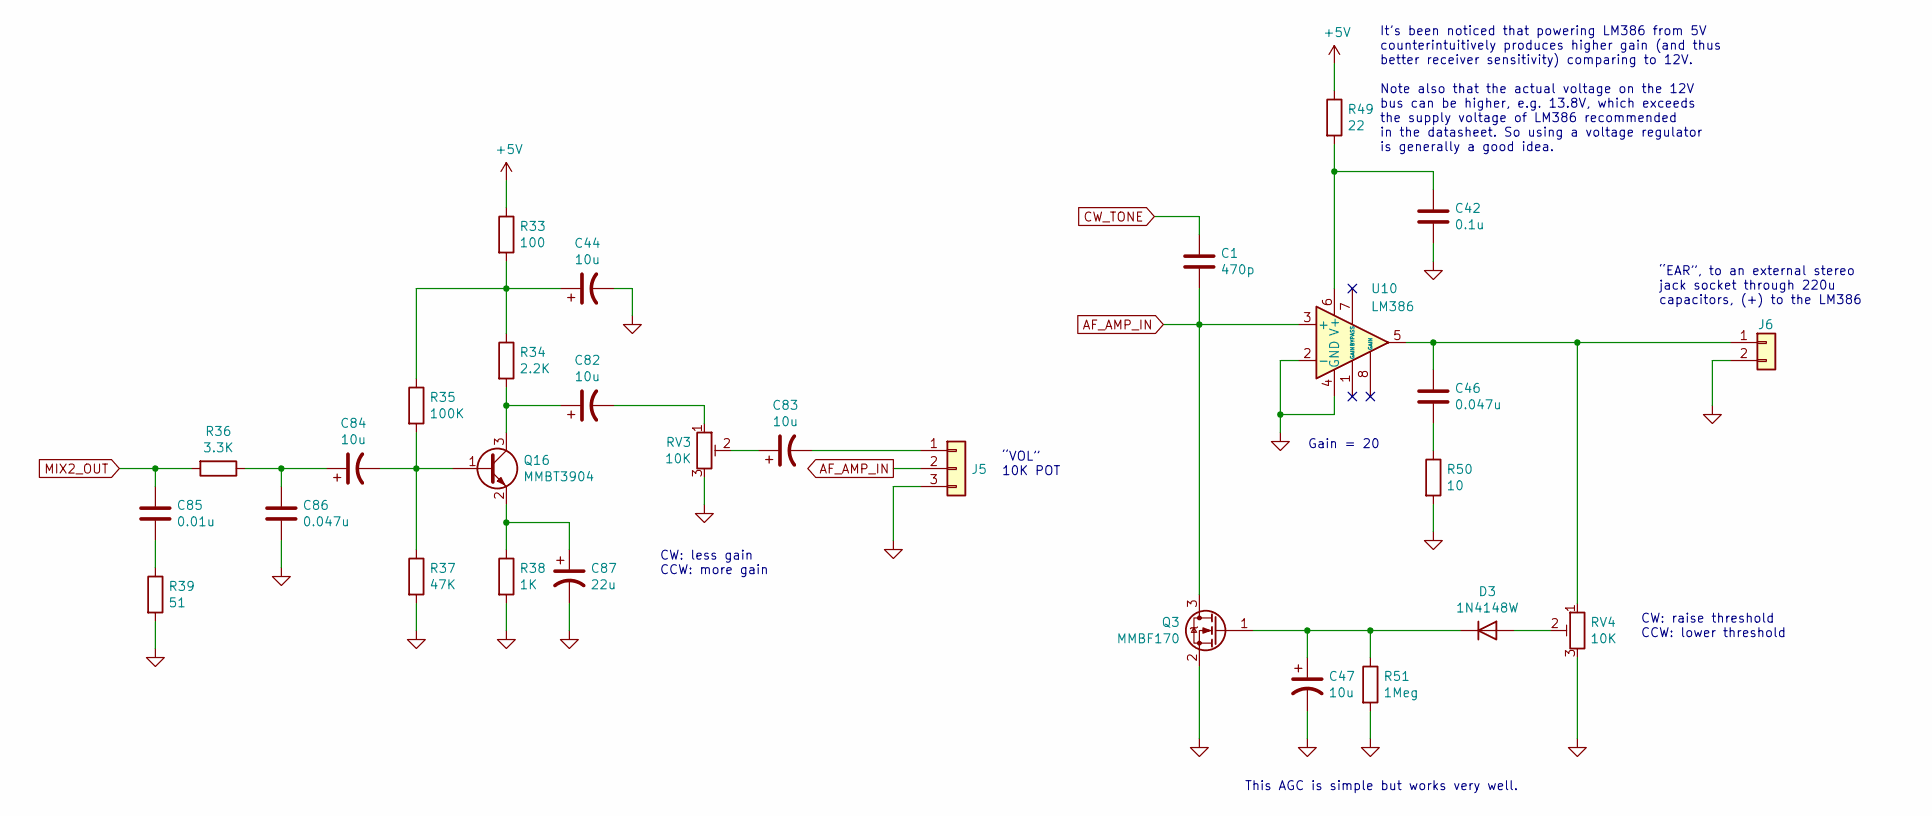
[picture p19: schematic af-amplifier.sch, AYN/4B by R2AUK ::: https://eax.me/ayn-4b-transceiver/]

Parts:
C1: 470p; C_0805_2012Metric_Pad1.15x1.40mm_HandSolder
C42: 0.1u; C_0805_2012Metric_Pad1.15x1.40mm_HandSolder
C44, C47, C82, C83, C84: 10u; CP_Elec_4x5.4
C46, C86: 0.047u; C_0805_2012Metric_Pad1.15x1.40mm_HandSolder
C85: 0.01u; C_0805_2012Metric_Pad1.15x1.40mm_HandSolder
C87: 22u; CP_Elec_5x5.4
D3: 1N4148W; D_SOD-123
J5: Conn_01x03; PinSocket_1x03_P2.54mm_Vertical
J6: Conn_01x02; PinSocket_1x02_P2.54mm_Vertical
Q3: MMBF170; SOT-23
Q16: MMBT3904; SOT-23
R33: 100; R_0805_2012Metric_Pad1.15x1.40mm_HandSolder
R34: 2.2K; R_0805_2012Metric_Pad1.15x1.40mm_HandSolder
R35: 100K; R_0805_2012Metric_Pad1.15x1.40mm_HandSolder
R36: 3.3K; R_0805_2012Metric_Pad1.15x1.40mm_HandSolder
R37: 47K; R_0805_2012Metric_Pad1.15x1.40mm_HandSolder
R38: 1K; R_0805_2012Metric_Pad1.15x1.40mm_HandSolder
R39: 51; R_0805_2012Metric_Pad1.15x1.40mm_HandSolder
R49: 22; R_0805_2012Metric_Pad1.15x1.40mm_HandSolder
R50: 10; R_0805_2012Metric_Pad1.15x1.40mm_HandSolder
R51: 1Meg; R_0805_2012Metric_Pad1.15x1.40mm_HandSolder
RV3, RV4: 10K; Potentiometer_Bourns_3296W_Vertical
U10: LM386; SO-8_5.3x6.2mm_P1.27mm

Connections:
+5V: R33.1, R49.1; also elsewhere on the board
AF_AMP_IN: C1.2, J5.2, Q3.3 (D), U10.3 (+)
CW_TONE: C1.1; also elsewhere on the board
GND: C42.2, C44.2, C47.2, C86.2, C87.2, J5.3, J6.2, Q3.2 (S), R37.2, R38.2, R39.2, R50.2, R51.2, RV3.3, RV4.3, U10.2 (-), U10.4 (GND); also elsewhere on the board
MIX2_OUT: C85.1, R36.2; also elsewhere on the board
unnamed: C42.1, R49.2, U10.6 (V+)
unnamed: C44.1, R33.2, R34.1, R35.1
unnamed: C46.1, J6.1, RV4.1, U10.5
unnamed: C46.2, R50.1
unnamed: C47.1, D3.1 (K), Q3.1 (G), R51.1
unnamed: C82.1, Q16.3 (C), R34.2
unnamed: C82.2, RV3.1
unnamed: C83.1, RV3.2
unnamed: C83.2, J5.1
unnamed: C84.1, C86.1, R36.1
unnamed: C84.2, Q16.1 (B), R35.2, R37.1
unnamed: C85.2, R39.1
unnamed: C87.1, Q16.2 (E), R38.1
unnamed: D3.2 (A), RV4.2

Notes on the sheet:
“EAR”, to an external stereo jack socket through 220u capacitors, (+) to the LM386
It’s been noticed that powering LM386 from 5V counterintuitively produces higher gain (and thus better receiver sensitivity) comparing to 12V. Note also that the actual voltage on the 12V bus can be higher, e.g. 13.8V, which exceeds the supply voltage of LM386 recommended in the datasheet. So using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
Gain = 20
This AGC is simple but works very well.
“VOL” 10K POT
CW: less gain CCW: more gain
CW: raise threshold CCW: lower threshold

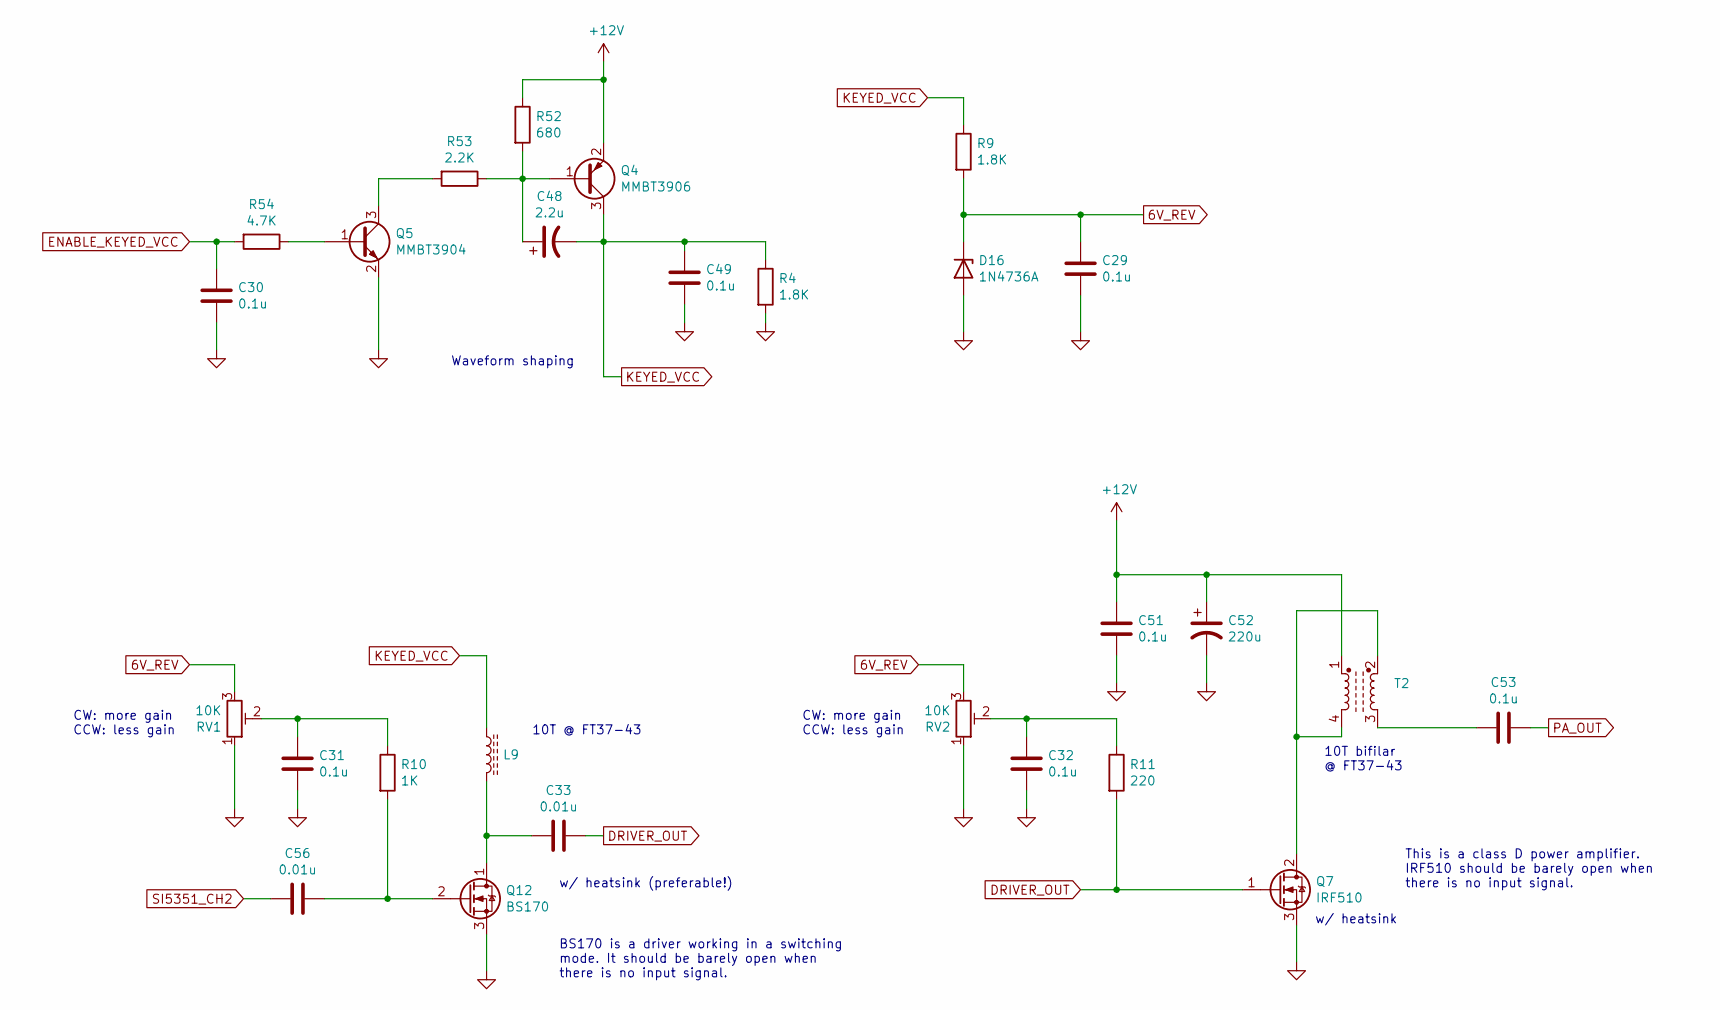
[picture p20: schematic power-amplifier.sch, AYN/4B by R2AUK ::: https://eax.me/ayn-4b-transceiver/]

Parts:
C29, C30, C31, C32, C49, C51, C53: 0.1u; C_0805_2012Metric_Pad1.15x1.40mm_HandSolder
C33, C56: 0.01u; C_0805_2012Metric_Pad1.15x1.40mm_HandSolder
C48: 2.2u; CP_Elec_4x5.4
C52: 220u; CP_Elec_8x10.5
D16: 1N4736A; D_DO-41_SOD81_P2.54mm_Vertical_AnodeUp
L9: FT37-43; Toroid_T37_Vertical_THD_L7.0mm_W6.5mm_P5.00mm
Q4: MMBT3906; SOT-23
Q5: MMBT3904; SOT-23
Q7: IRF510; TO-220-3_Vertical
Q12: BS170; TO-92_HandSolder
R4, R9: 1.8K; R_0805_2012Metric_Pad1.15x1.40mm_HandSolder
R10: 1K; R_0805_2012Metric_Pad1.15x1.40mm_HandSolder
R11: 220; R_0805_2012Metric_Pad1.15x1.40mm_HandSolder
R52: 680; R_0805_2012Metric_Pad1.15x1.40mm_HandSolder
R53: 2.2K; R_0805_2012Metric_Pad1.15x1.40mm_HandSolder
R54: 4.7K; R_0805_2012Metric_Pad1.15x1.40mm_HandSolder
RV1, RV2: 10K; Potentiometer_Bourns_3296W_Vertical
T2: FT37-43; DIP-4_W7.62mm

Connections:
6V_REV: C29.1, D16.1 (K), R9.2, RV1.3, RV2.3
+12V: C51.1, C52.1, Q4.2 (E), R52.1, T2.1; also elsewhere on the board
DRIVER_OUT: C33.1, Q7.1 (G), R11.2
ENABLE_KEYED_VCC: C30.1, R54.2; also elsewhere on the board
GND: C29.2, C30.2, C31.2, C32.2, C49.2, C51.2, C52.2, D16.2 (A), Q5.2 (E), Q7.3 (S), Q12.3 (S), R4.2, RV1.1, RV2.1; also elsewhere on the board
KEYED_VCC: C48.2, C49.1, L9.1, Q4.3 (C), R4.1, R9.1
unnamed: C31.1, R10.1, RV1.2
unnamed: C32.1, R11.1, RV2.2
unnamed: C33.2, L9.2, Q12.1 (D)
unnamed: C48.1, Q4.1 (B), R52.2, R53.1
unnamed: C53.2, T2.3
unnamed: C56.1, Q12.2 (G), R10.2
unnamed: Q5.1 (B), R54.1
unnamed: Q5.3 (C), R53.2
unnamed: Q7.2 (D), T2.2, T2.4
PA_OUT: C53.1; also elsewhere on the board
SI5351_CH2: C56.2; also elsewhere on the board

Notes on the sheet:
10T bifilar @ FT37-43
Waveform shaping
10T @ FT37-43
w/ heatsink
CW: more gain CCW: less gain
BS170 is a driver working in a switching mode. It should be barely open when there is no input signal.
This is a class D power amplifier. IRF510 should be barely open when there is no input signal.
w/ heatsink (preferable!)

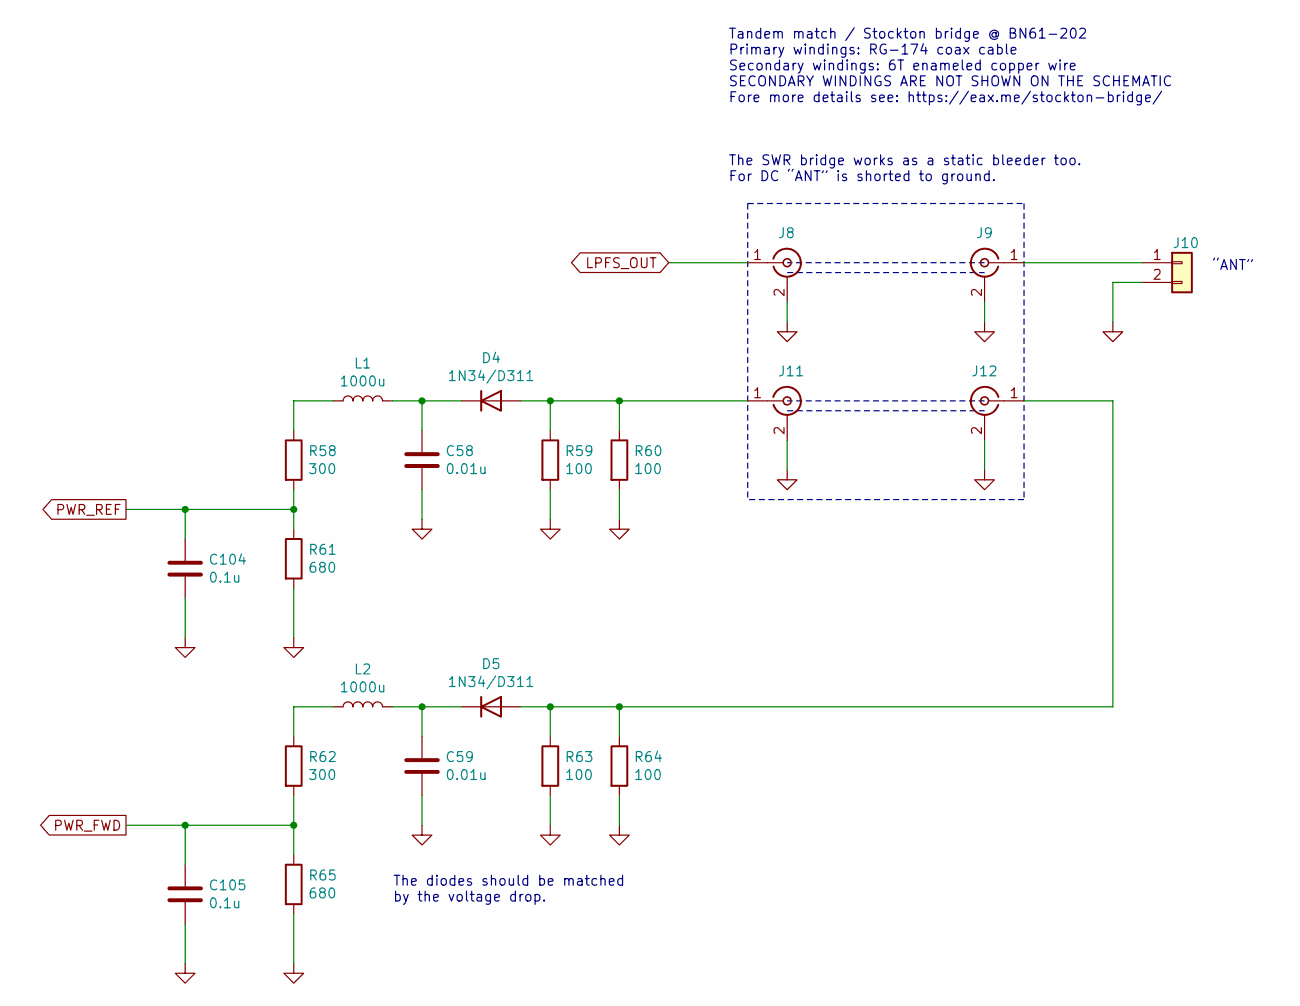
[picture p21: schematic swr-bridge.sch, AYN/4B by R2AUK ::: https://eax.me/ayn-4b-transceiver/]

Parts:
C58, C59: 0.01u; C_0805_2012Metric_Pad1.15x1.40mm_HandSolder
C104, C105: 0.1u; C_0805_2012Metric_Pad1.15x1.40mm_HandSolder
D4, D5: 1N34/D311; D_DO-41_SOD81_P2.54mm_Vertical_AnodeUp
J8, J9, J11, J12: Conn_Coaxial; PinSocket_1x02_P2.54mm_Vertical
J10: Conn_01x02; PinSocket_1x02_P2.54mm_Vertical
L1, L2: 1000u; D_DO-41_SOD81_P2.54mm_Vertical_AnodeUp
R58, R62: 300; R_0805_2012Metric_Pad1.15x1.40mm_HandSolder
R59, R60, R63, R64: 100; R_0805_2012Metric_Pad1.15x1.40mm_HandSolder
R61, R65: 680; R_0805_2012Metric_Pad1.15x1.40mm_HandSolder

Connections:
GND: C58.2, C59.2, C104.2, C105.2, J8.2 (Ext), J9.2 (Ext), J10.2, J11.2 (Ext), J12.2 (Ext), R59.2, R60.2, R61.2, R63.2, R64.2, R65.2; also elsewhere on the board
LPFS_OUT: J8.1 (In); also elsewhere on the board
unnamed: C58.1, D4.1 (K), L1.2
unnamed: C59.1, D5.1 (K), L2.2
unnamed: D4.2 (A), J11.1 (In), R59.1, R60.1
unnamed: D5.2 (A), J12.1 (In), R63.1, R64.1
unnamed: J9.1 (In), J10.1
unnamed: L1.1, R58.1
unnamed: L2.1, R62.1
PWR_FWD: C105.1, R62.2, R65.1; also elsewhere on the board
PWR_REF: C104.1, R58.2, R61.1; also elsewhere on the board

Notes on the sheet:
“ANT”
The SWR bridge works as a static bleeder too. For DC “ANT” is shorted to ground.
Tandem match / Stockton bridge @ BN61-202 Primary windings: RG-174 coax cable Secondary windings: 6T enameled copper wire SECONDARY WINDINGS ARE NOT SHOWN ON THE SCHEMATIC Fore more details see: https://eax.me/stockton-bridge/
The diodes should be matched by the voltage drop.

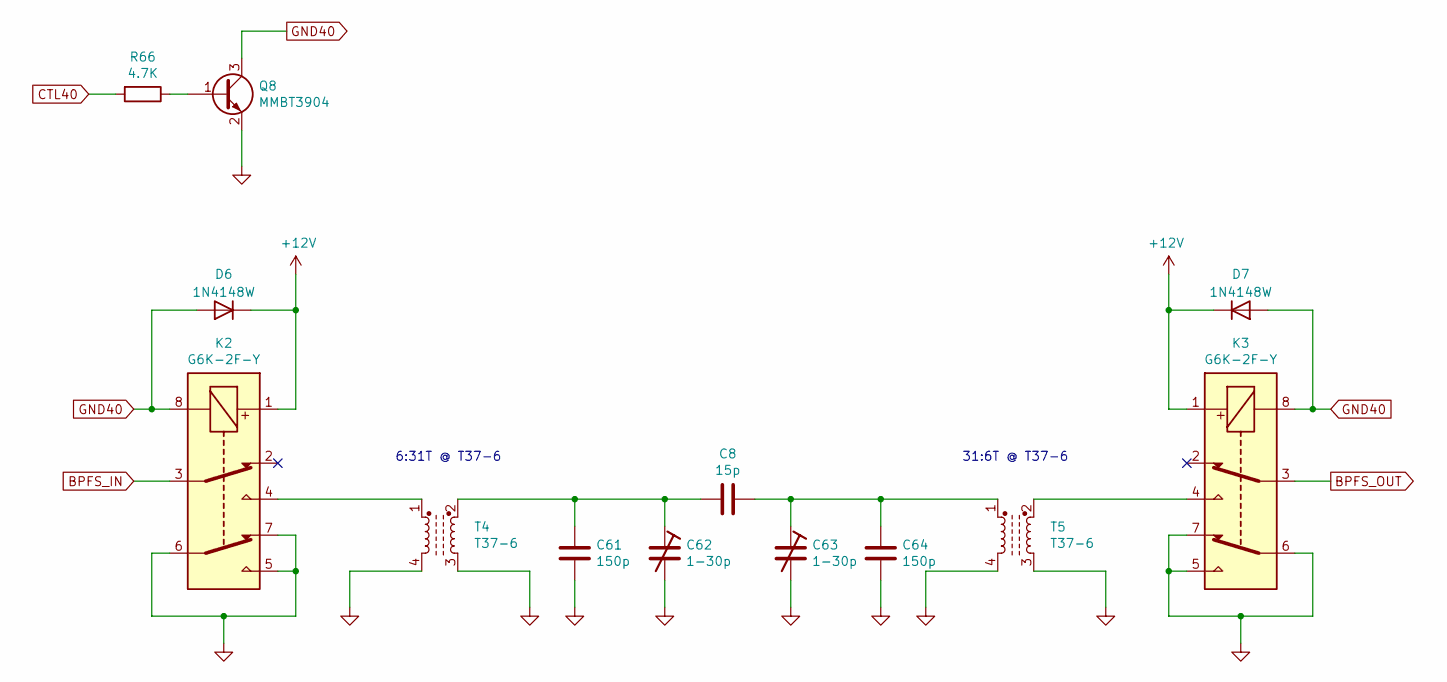
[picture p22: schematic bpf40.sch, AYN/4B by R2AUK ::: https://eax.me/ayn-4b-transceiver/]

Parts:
C8: 15p; C_0805_2012Metric_Pad1.15x1.40mm_HandSolder
C61, C64: 150p; C_0805_2012Metric_Pad1.15x1.40mm_HandSolder
C62, C63: 1-30p; C_Trim_THD_L7.0mm_W6.5mm_P5.00mm
D6, D7: 1N4148W; D_SOD-123
K2, K3: G6K-2F-Y; Relay_DPDT_Omron_G6K-2F-Y
Q8: MMBT3904; SOT-23
R66: 4.7K; R_0805_2012Metric_Pad1.15x1.40mm_HandSolder
T4, T5: T37-6; DIP-4_W7.62mm

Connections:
+12V: D6.1 (K), D7.1 (K), K2.1, K3.1; also elsewhere on the board
BPFS_IN: K2.3; also elsewhere on the board
BPFS_OUT: K3.3; also elsewhere on the board
CTL40: R66.2; also elsewhere on the board
GND: C61.2, C62.2, C63.2, C64.2, K2.5, K2.6, K2.7, K3.5, K3.6, K3.7, Q8.2 (E), T4.3, T4.4, T5.3, T5.4; also elsewhere on the board
GND40: D6.2 (A), D7.2 (A), K2.8, K3.8, Q8.3 (C)
unnamed: C8.2, C61.1, C62.1, T4.2
unnamed: C8.1, C63.1, C64.1, T5.1
unnamed: K2.4, T4.1
unnamed: K3.4, T5.2
unnamed: Q8.1 (B), R66.1

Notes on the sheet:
6:31T @ T37-6
31:6T @ T37-6

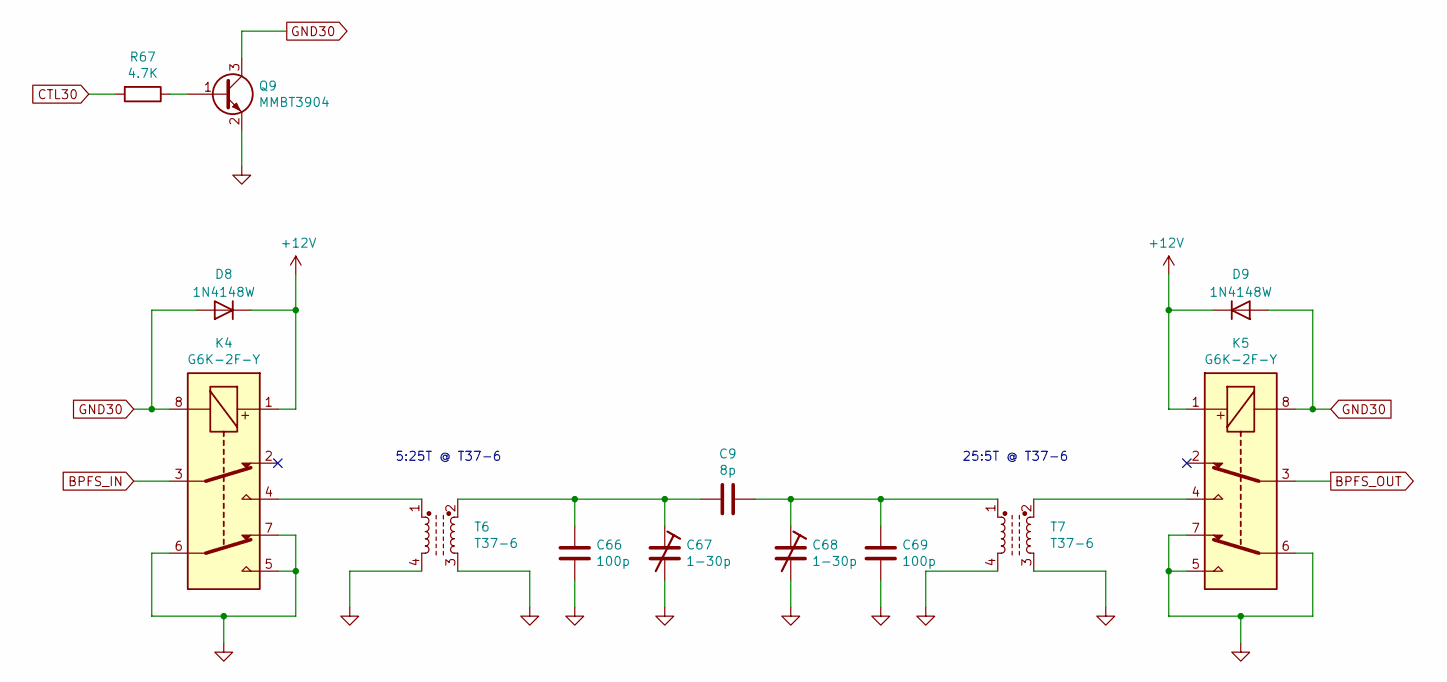
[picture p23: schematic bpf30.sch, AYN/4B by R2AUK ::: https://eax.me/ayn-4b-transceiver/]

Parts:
C9: 8p; C_0805_2012Metric_Pad1.15x1.40mm_HandSolder
C66, C69: 100p; C_0805_2012Metric_Pad1.15x1.40mm_HandSolder
C67, C68: 1-30p; C_Trim_THD_L7.0mm_W6.5mm_P5.00mm
D8, D9: 1N4148W; D_SOD-123
K4, K5: G6K-2F-Y; Relay_DPDT_Omron_G6K-2F-Y
Q9: MMBT3904; SOT-23
R67: 4.7K; R_0805_2012Metric_Pad1.15x1.40mm_HandSolder
T6, T7: T37-6; DIP-4_W7.62mm

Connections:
+12V: D8.1 (K), D9.1 (K), K4.1, K5.1; also elsewhere on the board
BPFS_IN: K4.3; also elsewhere on the board
BPFS_OUT: K5.3; also elsewhere on the board
CTL30: R67.2; also elsewhere on the board
GND: C66.2, C67.2, C68.2, C69.2, K4.5, K4.6, K4.7, K5.5, K5.6, K5.7, Q9.2 (E), T6.3, T6.4, T7.3, T7.4; also elsewhere on the board
GND30: D8.2 (A), D9.2 (A), K4.8, K5.8, Q9.3 (C)
unnamed: C9.2, C66.1, C67.1, T6.2
unnamed: C9.1, C68.1, C69.1, T7.1
unnamed: K4.4, T6.1
unnamed: K5.4, T7.2
unnamed: Q9.1 (B), R67.1

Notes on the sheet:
5:25T @ T37-6
25:5T @ T37-6

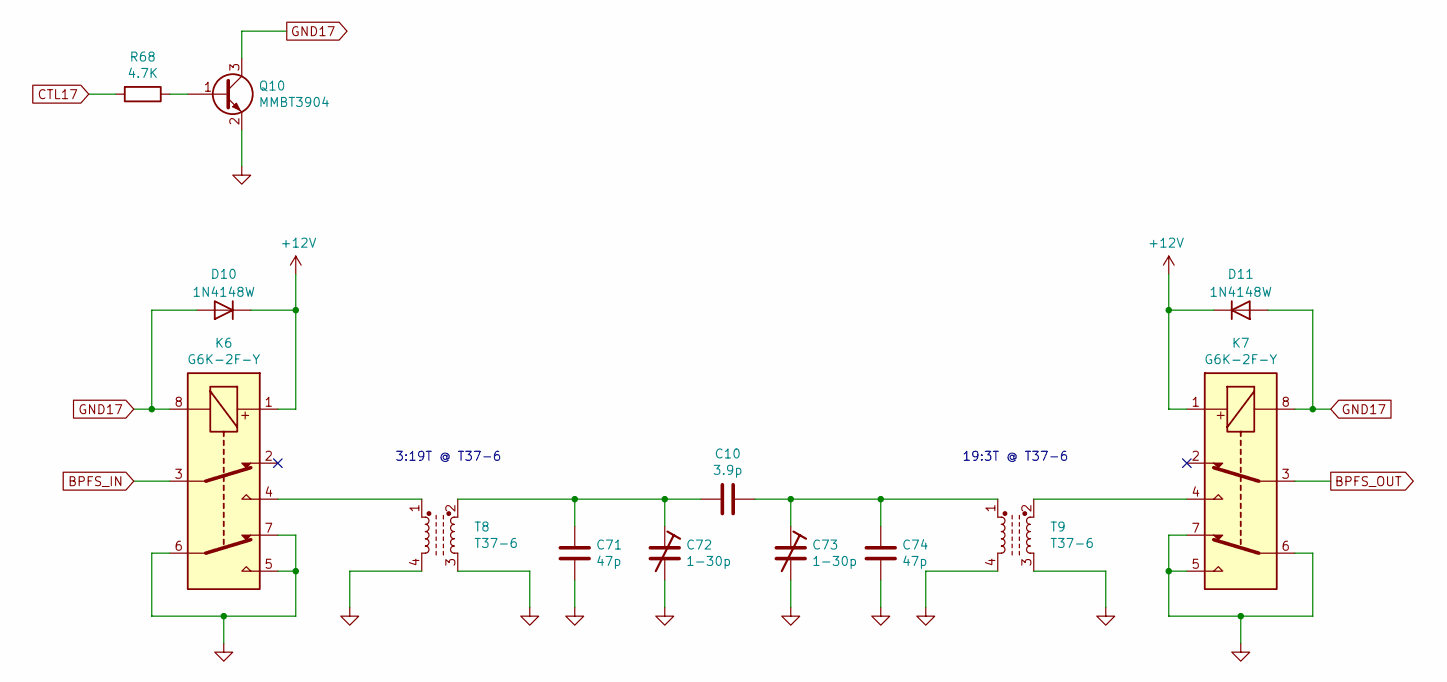
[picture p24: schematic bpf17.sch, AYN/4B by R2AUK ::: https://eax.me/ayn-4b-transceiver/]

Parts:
C10: 3.9p; C_0805_2012Metric_Pad1.15x1.40mm_HandSolder
C71, C74: 47p; C_0805_2012Metric_Pad1.15x1.40mm_HandSolder
C72, C73: 1-30p; C_Trim_THD_L7.0mm_W6.5mm_P5.00mm
D10, D11: 1N4148W; D_SOD-123
K6, K7: G6K-2F-Y; Relay_DPDT_Omron_G6K-2F-Y
Q10: MMBT3904; SOT-23
R68: 4.7K; R_0805_2012Metric_Pad1.15x1.40mm_HandSolder
T8, T9: T37-6; DIP-4_W7.62mm

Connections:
+12V: D10.1 (K), D11.1 (K), K6.1, K7.1; also elsewhere on the board
BPFS_IN: K6.3; also elsewhere on the board
BPFS_OUT: K7.3; also elsewhere on the board
CTL17: R68.2; also elsewhere on the board
GND: C71.2, C72.2, C73.2, C74.2, K6.5, K6.6, K6.7, K7.5, K7.6, K7.7, Q10.2 (E), T8.3, T8.4, T9.3, T9.4; also elsewhere on the board
GND17: D10.2 (A), D11.2 (A), K6.8, K7.8, Q10.3 (C)
unnamed: C10.1, C73.1, C74.1, T9.1
unnamed: C10.2, C71.1, C72.1, T8.2
unnamed: K6.4, T8.1
unnamed: K7.4, T9.2
unnamed: Q10.1 (B), R68.1

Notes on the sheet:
3:19T @ T37-6
19:3T @ T37-6

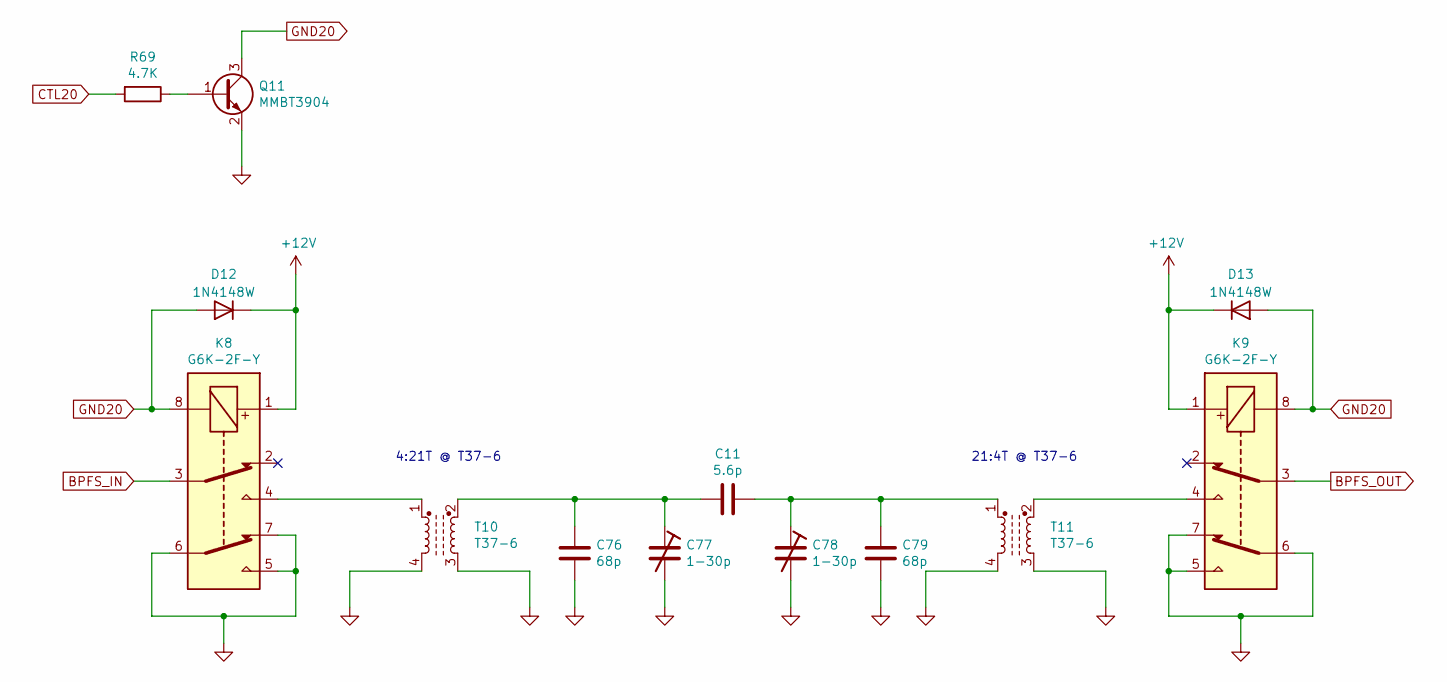
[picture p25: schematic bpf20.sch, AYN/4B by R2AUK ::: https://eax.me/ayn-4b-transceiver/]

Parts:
C11: 5.6p; C_0805_2012Metric_Pad1.15x1.40mm_HandSolder
C76, C79: 68p; C_0805_2012Metric_Pad1.15x1.40mm_HandSolder
C77, C78: 1-30p; C_Trim_THD_L7.0mm_W6.5mm_P5.00mm
D12, D13: 1N4148W; D_SOD-123
K8, K9: G6K-2F-Y; Relay_DPDT_Omron_G6K-2F-Y
Q11: MMBT3904; SOT-23
R69: 4.7K; R_0805_2012Metric_Pad1.15x1.40mm_HandSolder
T10, T11: T37-6; DIP-4_W7.62mm

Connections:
+12V: D12.1 (K), D13.1 (K), K8.1, K9.1; also elsewhere on the board
BPFS_IN: K8.3; also elsewhere on the board
BPFS_OUT: K9.3; also elsewhere on the board
CTL20: R69.2; also elsewhere on the board
GND: C76.2, C77.2, C78.2, C79.2, K8.5, K8.6, K8.7, K9.5, K9.6, K9.7, Q11.2 (E), T10.3, T10.4, T11.3, T11.4; also elsewhere on the board
GND20: D12.2 (A), D13.2 (A), K8.8, K9.8, Q11.3 (C)
unnamed: C11.1, C78.1, C79.1, T11.1
unnamed: C11.2, C76.1, C77.1, T10.2
unnamed: K8.4, T10.1
unnamed: K9.4, T11.2
unnamed: Q11.1 (B), R69.1

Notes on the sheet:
4:21T @ T37-6
21:4T @ T37-6

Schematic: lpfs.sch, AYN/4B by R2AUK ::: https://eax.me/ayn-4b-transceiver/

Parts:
C12, C25: 68p; C_0805_2012Metric_Pad1.15x1.40mm_HandSolder
C13, C15, C16, C17: 330p; C_0805_2012Metric_Pad1.15x1.40mm_HandSolder
C14: 220p; C_0805_2012Metric_Pad1.15x1.40mm_HandSolder
C18, C20, C21, C22, C23, C24: 150p; C_0805_2012Metric_Pad1.15x1.40mm_HandSolder
C19: 33p; C_0805_2012Metric_Pad1.15x1.40mm_HandSolder
C27, C28: 0.1u; C_0805_2012Metric_Pad1.15x1.40mm_HandSolder
D2, D15: 1N4148W; D_SOD-123
K10, K11: G6K-2F-Y; Relay_DPDT_Omron_G6K-2F-Y
L3, L4, L5, L6, L7, L8: T37-6; Toroid_T37_Vertical_THD_L7.0mm_W6.5mm_P5.00mm
Q2, Q6: MMBT3904; SOT-23
R5, R6: 4.7K; R_0805_2012Metric_Pad1.15x1.40mm_HandSolder

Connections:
+12V: D2.1 (K), D15.1 (K), K10.1, K11.1; also elsewhere on the board
CTL_LPFS_IN: C27.1, R5.2; also elsewhere on the board
CTL_LPFS_OUT: C28.1, R6.2; also elsewhere on the board
GND: C15.2, C16.2, C17.2, C18.2, C22.2, C23.2, C24.2, C25.2, C27.2, C28.2, K10.5, K10.6, K10.7, K11.5, K11.6, K11.7, Q2.2 (E), Q6.2 (E); also elsewhere on the board
GND_LPFS_IN: D2.2 (A), K10.8, Q2.3 (C)
GND_LPFS_OUT: D15.2 (A), K11.8, Q6.3 (C)
LPFS_IN: K10.3; also elsewhere on the board
LPFS_OUT: K11.3; also elsewhere on the board
LPF_20_17_IN: C19.2, C22.1, K10.4, L6.1
LPF_20_17_OUT: C21.1, C25.1, K11.2, L8.2
LPF_40_30_IN: C12.2, C15.1, K10.2, L3.1
LPF_40_30_OUT: C14.1, C18.1, K11.4, L5.2
unnamed: C12.1, C13.2, C16.1, L3.2, L4.1
unnamed: C13.1, C14.2, C17.1, L4.2, L5.1
unnamed: C19.1, C20.2, C23.1, L6.2, L7.1
unnamed: C20.1, C21.2, C24.1, L7.2, L8.1
unnamed: Q2.1 (B), R5.1
unnamed: Q6.1 (B), R6.1

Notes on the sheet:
16T @ T37-6
12T @ T37-6
13T @ T37-6
11T @ T37-6
8T @ T37-6
9T @ T37-6

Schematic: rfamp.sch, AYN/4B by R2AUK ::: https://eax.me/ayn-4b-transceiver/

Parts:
C2, C34, C35, C36, C37: 0.1u; C_0805_2012Metric_Pad1.15x1.40mm_HandSolder
D17: 1N4148W; D_SOD-123
J7: Conn_01x02; PinSocket_1x02_P2.54mm_Vertical
K12: G6K-2F-Y; Relay_DPDT_Omron_G6K-2F-Y
Q13: MMBT3904; SOT-23
R12: 22; R_0805_2012Metric_Pad1.15x1.40mm_HandSolder
R13: 3.3K; R_0805_2012Metric_Pad1.15x1.40mm_HandSolder
R14: 1.3K; R_0805_2012Metric_Pad1.15x1.40mm_HandSolder
R15: 68; R_0805_2012Metric_Pad1.15x1.40mm_HandSolder
R16: 1K; R_0805_2012Metric_Pad1.15x1.40mm_HandSolder
R17: 6.2; R_0805_2012Metric_Pad1.15x1.40mm_HandSolder
T1: FT37-43; DIP-4_W7.62mm

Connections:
+12V: D17.1 (K), K12.1, R12.1; also elsewhere on the board
BPFS_OUT: K12.3; also elsewhere on the board
GND: C2.2, J7.2, R15.2, R16.2, R17.2; also elsewhere on the board
MIX1_IN: K12.6; also elsewhere on the board
unnamed: C2.1, R12.2, T1.2
unnamed: C34.1, Q13.3 (C), R13.1, T1.4
unnamed: C34.2, R13.2, R14.1
unnamed: C35.2, T1.1, T1.3
unnamed: C36.1, Q13.1 (B), R14.2, R16.1
unnamed: C37.1, Q13.2 (E), R15.1
unnamed: C37.2, R17.1
unnamed: D17.2 (A), J7.1, K12.8
RFAMP_BYPASS: K12.4, K12.5
RFAMP_IN: C36.2, K12.2
RFAMP_OUT: C35.1, K12.7

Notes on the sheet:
“RFAMP” switch
10T bifilar @ FT37-43

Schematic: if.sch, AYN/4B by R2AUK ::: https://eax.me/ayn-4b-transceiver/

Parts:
C38, C39, C40, C41, C43, C45, C50, C54, C55, C57, C81: 0.1u; C_0805_2012Metric_Pad1.15x1.40mm_HandSolder
C60, C65, C70, C75, C80, C98: 270p; C_0805_2012Metric_Pad1.15x1.40mm_HandSolder
C93, C94: 470p; C_0805_2012Metric_Pad1.15x1.40mm_HandSolder
C95, C96: 220p; C_0805_2012Metric_Pad1.15x1.40mm_HandSolder
L10, L11: T37-6; L_Toroid_Horizontal_D9.5mm_P15.00mm_Diameter10-5mm_Amidon-T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
Q14, Q15: MMBT3904; SOT-23
R18, R19: 22; R_0805_2012Metric_Pad1.15x1.40mm_HandSolder
R20, R22: 3.3K; R_0805_2012Metric_Pad1.15x1.40mm_HandSolder
R21, R23: 1.3K; R_0805_2012Metric_Pad1.15x1.40mm_HandSolder
R24, R26: 68; R_0805_2012Metric_Pad1.15x1.40mm_HandSolder
R25, R27: 1K; R_0805_2012Metric_Pad1.15x1.40mm_HandSolder
R28, R29: 6.2; R_0805_2012Metric_Pad1.15x1.40mm_HandSolder
R30, R31: 150; R_0805_2012Metric_Pad1.15x1.40mm_HandSolder
R32: 36; R_0805_2012Metric_Pad1.15x1.40mm_HandSolder
T3, T12: FT37-43; DIP-4_W7.62mm
U3, U4: ADE-6; Mini-Circuits_CD542_LandPatternPL-052
Y1, Y2, Y3, Y4, Y5: 9.000; Crystal_HC49-U_Vertical

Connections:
+12V: R18.1, R19.1; also elsewhere on the board
ANALOG_BFO: C93.1, L10.1; also elsewhere on the board
ATT_IN: C50.1, R30.2, R32.1
BUFFER_IN: C54.2, U3.2 (IF)
GND: C38.2, C39.2, C70.2, C75.2, C80.2, C93.2, C94.2, C95.2, C96.2, C98.2, R24.2, R25.2, R26.2, R27.2, R28.2, R29.2, R30.1, R31.1, U3.1 (GND), U3.4 (GND), U3.5 (GND), U4.1 (GND), U4.4 (GND), U4.5 (GND); also elsewhere on the board
IFAMP_IN: C65.1, Q14.1 (B), R21.2, R25.1
IFAMP_OUT: C45.1, U4.3 (RF)
MIX1_IN: U3.3 (RF); also elsewhere on the board
MIX2_OUT: U4.2 (IF); also elsewhere on the board
unnamed: C38.1, R18.2, T3.2
unnamed: C39.1, R19.2, T12.2
unnamed: C40.1, Q14.3 (C), R20.1, T3.4
unnamed: C40.2, R20.2, R21.1
unnamed: C41.1, U3.6 (LO)
unnamed: C41.2, C96.1, L11.2
unnamed: C43.1, Q15.3 (C), R22.1, T12.4
unnamed: C43.2, R22.2, R23.1
unnamed: C45.2, T3.1, T3.3
unnamed: C50.2, T12.1, T12.3
unnamed: C54.1, Q15.1 (B), R23.2, R27.1
unnamed: C55.1, Q14.2 (E), R24.1
unnamed: C55.2, R28.1
unnamed: C57.1, Q15.2 (E), R26.1
unnamed: C57.2, R29.1
unnamed: C60.1, Y1.1
unnamed: C65.2, Y5.2
unnamed: C70.1, Y1.2, Y2.1
unnamed: C75.1, Y2.2, Y3.1
unnamed: C80.1, Y3.2, Y4.1
unnamed: C81.1, U4.6 (LO)
unnamed: C81.2, C94.1, L10.2
unnamed: C98.1, Y4.2, Y5.1
SI5351_CH0: C95.1, L11.1; also elsewhere on the board
XFLTR_IN: C60.2, R31.2, R32.2

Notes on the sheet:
10T bifilar @ FT37-43
6 dB attenuator
High-Q (>= 100 000) crystals are required to get a narrowband CW filter with low losses. The crystals should be measured using G3UUR method and matched by the resonant frequency. Use LTspice to find the right capacitance for your crystals.
16T @ T37-6
7T @ T37-6
VFO
LPF 30 MHz
LPF 11 MHz

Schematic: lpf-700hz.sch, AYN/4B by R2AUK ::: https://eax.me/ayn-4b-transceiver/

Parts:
C88, C89, C90, C91, C92, C97: 0.1u; C_0805_2012Metric_Pad1.15x1.40mm_HandSolder
R40, R45: 100K; R_0805_2012Metric_Pad1.15x1.40mm_HandSolder
R41, R42, R43, R44: 1.8K; R_0805_2012Metric_Pad1.15x1.40mm_HandSolder
U5: NE5532; SOIC-8_5.23x5.23mm_P1.27mm

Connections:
+5V: C97.1, R40.1, U5.8 (V+); also elsewhere on the board
CW_TONE: C89.1, U5.6 (-), U5.7; also elsewhere on the board
GND: C91.2, C92.2, C97.2, R45.2, U5.4 (V-); also elsewhere on the board
unnamed: C88.1, R41.2, U5.1, U5.2 (-)
unnamed: C88.2, R43.1, R44.2
unnamed: C89.2, R41.1, R42.2
unnamed: C90.1, R40.2, R43.2, R45.1
unnamed: C91.1, R44.1, U5.3 (+)
unnamed: C92.1, R42.1, U5.5 (+)
PWM_700HZ: C90.2; also elsewhere on the board

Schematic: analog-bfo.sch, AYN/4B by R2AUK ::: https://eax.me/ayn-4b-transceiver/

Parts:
C99, C102: 0.1u; C_0805_2012Metric_Pad1.15x1.40mm_HandSolder
C100, C101: 150p; C_0805_2012Metric_Pad1.15x1.40mm_HandSolder
C103: 1-30p; C_Trim_THD_L7.0mm_W6.5mm_P5.00mm
L12: 18u; D_DO-41_SOD81_P2.54mm_Vertical_AnodeUp
Q17, Q18: MMBT3904; SOT-23
R46: 22; R_0805_2012Metric_Pad1.15x1.40mm_HandSolder
R47, R55: 10K; R_0805_2012Metric_Pad1.15x1.40mm_HandSolder
R48, R56, R57: 1K; R_0805_2012Metric_Pad1.15x1.40mm_HandSolder
Y6: 9.000; Crystal_HC49-U_Vertical

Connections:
+12V: R46.1; also elsewhere on the board
ANALOG_BFO: C102.1; also elsewhere on the board
GND: C99.2, C101.2, C103.2, R55.2, R56.2, R57.2; also elsewhere on the board
unnamed: C99.1, Q17.3 (C), Q18.3 (C), R46.2, R47.1
unnamed: C100.1, Q17.1 (B), R47.2, R55.1, Y6.2
unnamed: C100.2, C101.1, Q17.2 (E), R48.2, R56.1
unnamed: C102.2, Q18.2 (E), R57.1
unnamed: C103.1, L12.1
unnamed: L12.2, Y6.1
unnamed: Q18.1 (B), R48.1

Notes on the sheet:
The oscillator should be tuned to: (crystal filter center frequency) - 700 Hz Example: Filter CF = 8.998.280 Hz Osc. Freq = 8.997.580 Hz The expected output power to 50 Ohms is about 4 dBm on the main frequency (probably, mismatched). This is not exactly 7 dBm typically required for a double balanc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
The secret of a superheterodyne receiver free of spurious signals is a clean BFO. The signal of Si5351 is way too dirty and can’t be used as a BFO. Trust me, I’ve tried many times.

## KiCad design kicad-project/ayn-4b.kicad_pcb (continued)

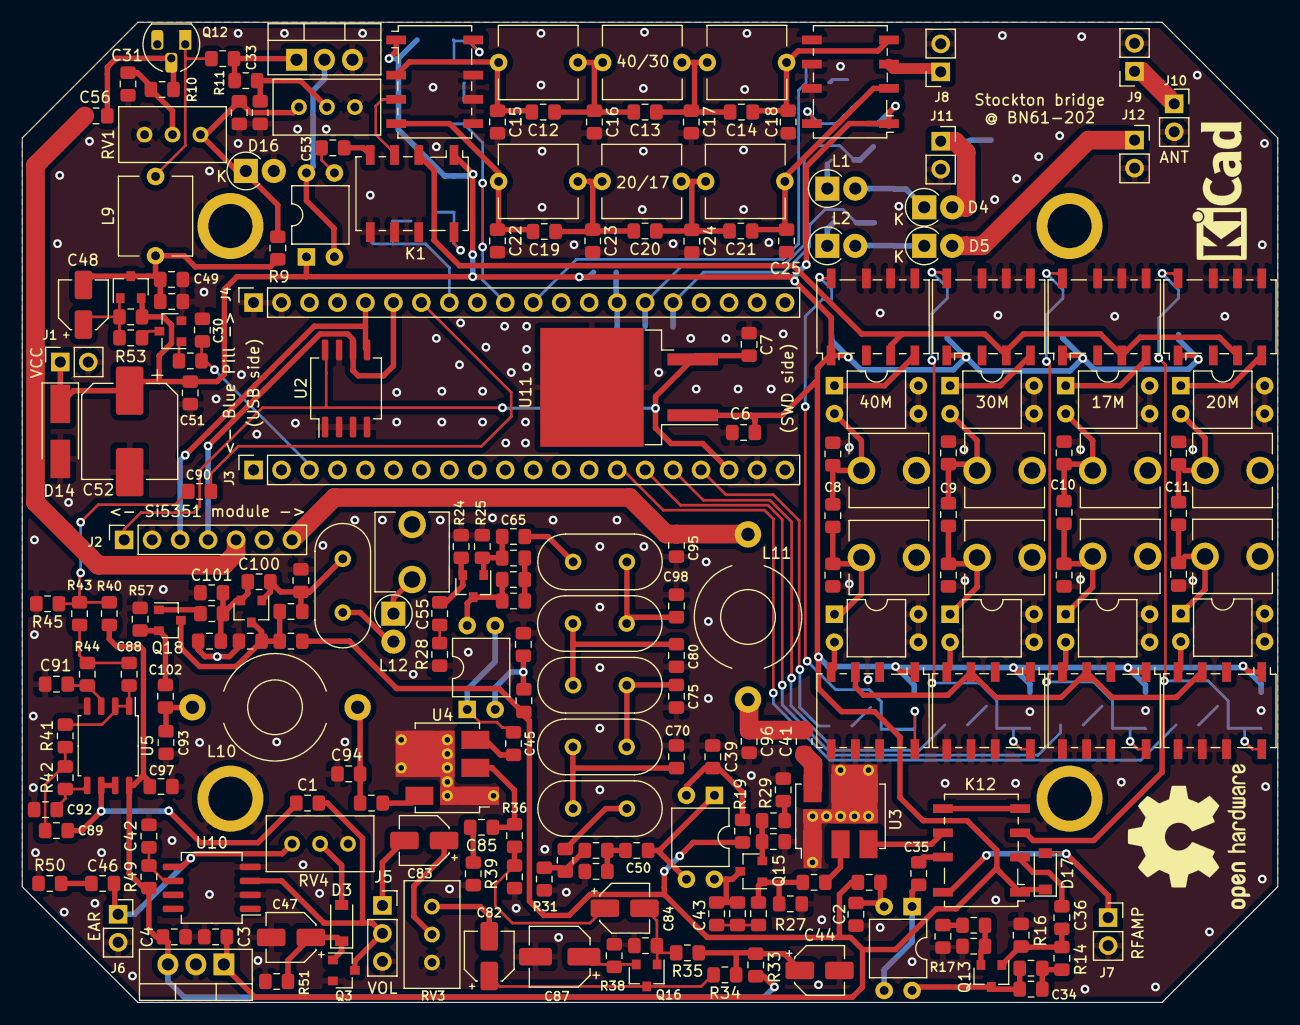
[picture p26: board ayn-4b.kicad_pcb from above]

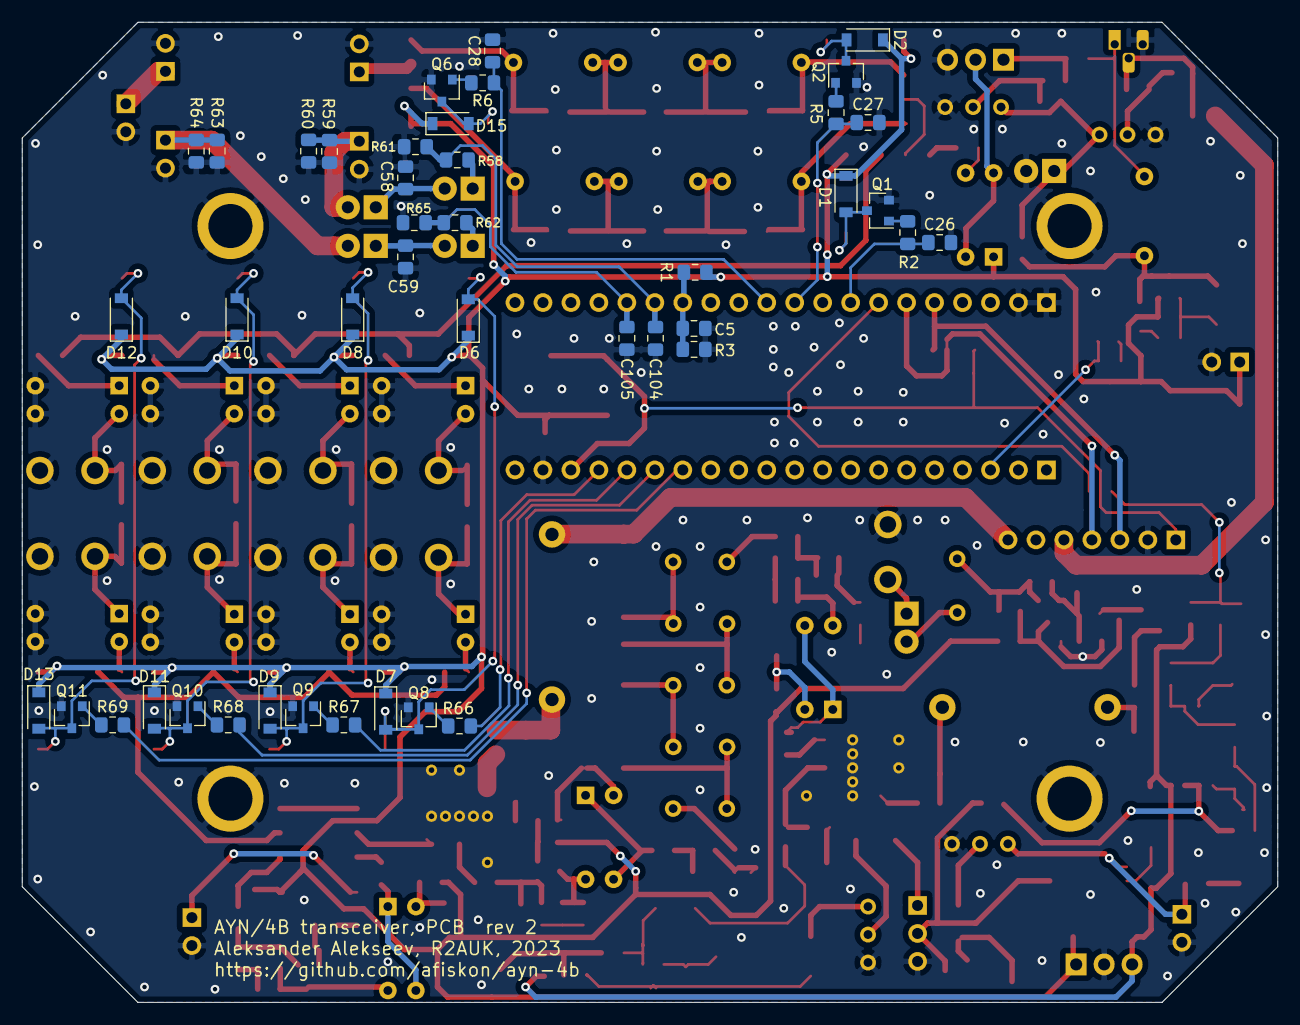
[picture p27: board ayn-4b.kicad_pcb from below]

Board: 2 copper layers, 114.0 x 89.0 mm, 278 parts (43 on the bottom side), 153 nets.

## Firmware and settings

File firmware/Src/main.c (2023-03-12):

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

/* Includes ------------------------------------------------------------------*/
#include "main.h"

/* USER CODE BEGIN Includes */
#include <string.h>
#include <stdlib.h>
#include <stdbool.h>
#include "si5351.h"
#include "lcd.h"

/* USER CODE END Includes */

ADC_HandleTypeDef hadc1;

I2C_HandleTypeDef hi2c2;

TIM_HandleTypeDef htim1;
TIM_HandleTypeDef htim2;
TIM_HandleTypeDef htim3;

/* USER CODE BEGIN PV */

/* USER CODE END PV */

void SystemClock_Config(void);
static void MX_GPIO_Init(void);
static void MX_ADC1_Init(void);
static void MX_I2C2_Init(void);
static void MX_TIM1_Init(void);
static void MX_TIM2_Init(void);
static void MX_TIM3_Init(void);
/* USER CODE BEGIN PFP */

/* USER CODE END PFP */

/* USER CODE BEGIN 0 */

#define CH_VFO  0
#define CH_CAL  1
#define CH_CW   2

#define VFO_DRIVE_STRENGTH SI5351_DRIVE_STRENGTH_4MA
#define BFO_DRIVE_STRENGTH SI5351_DRIVE_STRENGTH_4MA

const int32_t XtalFilterCenterFrequency = 8998230;
const int32_t si5351_correction = -2610;

/* Adjust for used rotary encoders */
#define MAIN_DELTA_DIV 1
#define MAIN_DELTA_MULT 1
#define MULTI_DELTA_DIV 1
#define MULTI_DELTA_MULT 1

int32_t Fvfo = 1000000; // dummy value, will be changed below

const uint8_t eeprom_i2c_addr = (0x50 << 1);
#define EEPROM_PAGE_SIZE 32
#define KEYER_CONFIG_EEPROM_ADDR        0x0000
#define KEYER_MESSAGE_EEPROM_ADDR       0x0400

typedef enum {
    CLAR_MODE_DISABLED = 0,
    CLAR_MODE_RIT = 1,
    CLAR_MODE_XIT = 2,
} ClarMode_t;

bool lockMode = false;
bool fastMode = false;
ClarMode_t clarMode = CLAR_MODE_DISABLED;

int32_t clarOffset = 0;

typedef enum {
    CW_SEND_NONE = 0,
    CW_SEND_DIT = 1,
    CW_SEND_DAH = 2,
} CwSend_t;

CwSend_t lastSent = CW_SEND_NONE;
CwSend_t nextSend = CW_SEND_NONE;

typedef enum {
    KEYER_SETINGS_PAGE_SPEED = 0,
    KEYER_SETINGS_PAGE_XMIT = 1,
    KEYER_SETINGS_PAGE_SAVE = 2,
    KEYER_SETINGS_PAGE_PLAY = 3,
} KeyerSettingsPage_t;

typedef struct {
    uint16_t checksum;
    bool straightKey;
    int32_t speedWPM;
    int32_t ditTimeMs;
    KeyerSettingsPage_t settingsPage;
} KeyerConfig_t;

KeyerConfig_t keyerConfig = {
    .checksum = 0,
    .straightKey = false,
    .speedWPM = 19,

    // ditTimeMs = 60*1000/(50*WPM)
    // where 50 is the length in dits of "PARIS "
    // see https://morsecode.world/international/timing.html
    .ditTimeMs = 63,
    .settingsPage = KEYER_SETINGS_PAGE_SPEED,
};

#define MAX_KEYER_MESSAGE_LENGTH 500

typedef struct {
    uint16_t checksum;
    uint16_t length;
    char message[MAX_KEYER_MESSAGE_LENGTH];
} KeyerMessage_t;

KeyerMessage_t keyerMessage = {
    .checksum = 0,
    .length = 0,
};

bool inTransmitMode = false;
bool inCWPlaybackOnlyMode = false;

#define BUTTON_DEBOUNCE_TIME_MS 200
typedef enum {
    BUTTON_STATUS_PRESSED = 0,
    BUTTON_STATUS_RELEASED = 1,
    BUTTON_STATUS_DEBOUNCE = 2,
} ButtonStatus_t;

typedef enum {
    USE_LPF_40_30 = 0,
    USE_LPF_20_17 = 1,
} UseLPF_t;

typedef enum {
    USE_BPF_NONE = 0,
    USE_BPF_40 = 1,
    USE_BPF_30 = 2,
    USE_BPF_20 = 3,
    USE_BPF_17 = 4,
} UseBPF_t;

typedef struct {
    int32_t minFreq;
    int32_t maxFreq;
    int32_t lastFreq;
    UseLPF_t lpf;
    UseBPF_t bpf;
    si5351DriveStrength_t txDriveStrength;
} BandInfo_t;

int32_t currentBand = 2; // default: 20m

BandInfo_t bands[] = {
    {
        .minFreq  = 7000000,
        .maxFreq  = 7040000,
        .lastFreq = 7030000,
        .lpf = USE_LPF_40_30,
        .bpf = USE_BPF_40,
        .txDriveStrength = SI5351_DRIVE_STRENGTH_2MA,
    },
    {
        .minFreq  = 10100000,
        .maxFreq  = 10130000,
        .lastFreq = 10116000,
        .lpf = USE_LPF_40_30,
        .bpf = USE_BPF_30,
        .txDriveStrength = SI5351_DRIVE_STRENGTH_8MA,
    },
    {
        .minFreq  = 14000000,
        .maxFreq  = 14070000,
        .lastFreq = 14060000,
        .lpf = USE_LPF_20_17,
        .bpf = USE_BPF_20,
        .txDriveStrength = SI5351_DRIVE_STRENGTH_8MA,
    },
    {
        .minFreq  = 18068000,
        .maxFreq  = 18095000,
        .lastFreq = 18086000,
        .lpf = USE_LPF_20_17,
        .bpf = USE_BPF_17,
        .txDriveStrength = SI5351_DRIVE_STRENGTH_8MA,
    },
};

void ADC_Select_Channel(uint32_t ch) {
    ADC_ChannelConfTypeDef conf = {
        .Channel = ch,
        .Rank = ADC_REGULAR_RANK_1,
        .SamplingTime = ADC_SAMPLETIME_28CYCLES_5,
    };
    if (HAL_ADC_ConfigChannel(&hadc1, &conf) != HAL_OK) {
        Error_Handler();
    }
} 

double ADC_ReadVoltage(uint32_t ch) {
    ADC_Select_Channel(ch);
    HAL_ADC_PollForConversion(&hadc1, HAL_MAX_DELAY);
    return ((double)HAL_ADC_GetValue(&hadc1))*3.3/4096.0;
}

// http://en.wikipedia.org/wiki/Jenkins_hash_function
uint32_t jenkinsHash(const uint8_t *data, const size_t len) {
  uint32_t hash, i;
  for(hash = i = 0; i < len; ++i) {
    hash += data[i];
    hash += (hash << 10);
    hash ^= (hash >> 6);
  }
  hash += (hash << 3);
  hash ^= (hash >> 11);
  hash += (hash << 15);
  return hash;
}

void loadKeyerMessage() {
    HAL_StatusTypeDef status;
    uint16_t savedChecksum;
    KeyerMessage_t savedKeyerMessage;

    for(;;) {
        status = HAL_I2C_IsDeviceReady(&hi2c2, eeprom_i2c_addr, 3, HAL_MAX_DELAY);
        if(status == HAL_OK)
            break;
    }

    HAL_I2C_Mem_Read(&hi2c2, eeprom_i2c_addr, KEYER_MESSAGE_EEPROM_ADDR, I2C_MEMADD_SIZE_16BIT,
            (uint8_t*)&savedKeyerMessage, sizeof(savedKeyerMessage), HAL_MAX_DELAY);

    savedChecksum = savedKeyerMessage.checksum;
    savedKeyerMessage.checksum = 0;

    if((jenkinsHash((const uint8_t*)&savedKeyerMessage, sizeof(savedKeyerMessage)) & 0xFFFF) == savedChecksum) {
        keyerMessage = savedKeyerMessage;
    } else {
        LCD_Goto(0, 0);
        LCD_SendString("MSG HASH");
        LCD_Goto(1, 0);
        LCD_SendString(" ERROR! ");
        HAL_Delay(2000);
        LCD_Clear();
    }
}

void saveKeyerMessage() {
    HAL_StatusTypeDef status;
    uint16_t checksum;
    size_t bytes_to_write = sizeof(keyerMessage);
    uint8_t* struct_offset = (uint8_t*)&keyerMessage;
    uint16_t eeprom_addr = KEYER_MESSAGE_EEPROM_ADDR;

    keyerMessage.checksum = 0;
    checksum = (jenkinsHash((const uint8_t*)&keyerMessage, sizeof(keyerMessage)) & 0xFFFF);
    keyerMessage.checksum = checksum;

    // sizeof(keyerMessage) exceeds EEPROM_PAGE_SIZE
    // so we have to write it in batches
    while(bytes_to_write > 0) {
        size_t batch_size = bytes_to_write;
        if(batch_size > EEPROM_PAGE_SIZE) {
            batch_size = EEPROM_PAGE_SIZE;
        }

        for(;;) {
            status = HAL_I2C_IsDeviceReady(&hi2c2, eeprom_i2c_addr, 3, HAL_MAX_DELAY);
            if(status == HAL_OK)
                break;
        }

        HAL_I2C_Mem_Write(&hi2c2, eeprom_i2c_addr, eeprom_addr, I2C_MEMADD_SIZE_16BIT,
            struct_offset, batch_size, HAL_MAX_DELAY);

        bytes_to_write -= batch_size;
        struct_offset += batch_size;
        eeprom_addr += batch_size;
    }
}

void loadKeyerConfig() {
    HAL_StatusTypeDef status;
    uint16_t savedChecksum;
    KeyerConfig_t savedKeyerConfig;

    for(;;) {
        status = HAL_I2C_IsDeviceReady(&hi2c2, eeprom_i2c_addr, 3, HAL_MAX_DELAY);
        if(status == HAL_OK)
            break;
    }

    HAL_I2C_Mem_Read(&hi2c2, eeprom_i2c_addr, KEYER_CONFIG_EEPROM_ADDR, I2C_MEMADD_SIZE_16BIT,
        (uint8_t*)&savedKeyerConfig, sizeof(savedKeyerConfig), HAL_MAX_DELAY);

    savedChecksum = savedKeyerConfig.checksum;
    savedKeyerConfig.checksum = 0;

    if((jenkinsHash((const uint8_t*)&savedKeyerConfig, sizeof(savedKeyerConfig)) & 0xFFFF) == savedChecksum) {
        keyerConfig = savedKeyerConfig;
    } else {
        LCD_Goto(0, 0);
        LCD_SendString("CFG HASH");
        LCD_Goto(1, 0);
        LCD_SendString(" ERROR! ");
        HAL_Delay(2000);
        LCD_Clear();
    }
}

void saveKeyerConfig() {
    HAL_StatusTypeDef status;
    uint16_t checksum;
    keyerConfig.checksum = 0;

    checksum = (jenkinsHash((const uint8_t*)&keyerConfig, sizeof(keyerConfig)) & 0xFFFF);
    keyerConfig.checksum = checksum;

    for(;;) {
        status = HAL_I2C_IsDeviceReady(&hi2c2, eeprom_i2c_addr, 3, HAL_MAX_DELAY);
        if(status == HAL_OK)
            break;
    }

    HAL_I2C_Mem_Write(&hi2c2, eeprom_i2c_addr, KEYER_CONFIG_EEPROM_ADDR, I2C_MEMADD_SIZE_16BIT,
        (uint8_t*)&keyerConfig, sizeof(keyerConfig), HAL_MAX_DELAY);
}

void changeKeyerSpeed(int32_t delta) {
    keyerConfig.speedWPM += delta;
    if(keyerConfig.speedWPM < 10) {
        keyerConfig.speedWPM = 10;
        keyerConfig.straightKey = true;
        keyerConfig.ditTimeMs = 60*1000/(50*(10+1)); // as for 10 WPM
    } else {
        keyerConfig.straightKey = false;
        if(keyerConfig.speedWPM > 30) {
            keyerConfig.speedWPM = 30;
        }

        /* +1 compensates the signal rise/fall time */
        keyerConfig.ditTimeMs = 60*1000/(50*(keyerConfig.speedWPM + 1));
    }
}

void SetupCLK(uint8_t output, int32_t Fclk, si5351DriveStrength_t driveStrength) {
    static bool pllSetupDone = false;
    si5351PLLConfig_t pll_conf;
    si5351OutputConfig_t out_conf;

    si5351_Calc(Fclk, &pll_conf, &out_conf);
    if(!pllSetupDone) {
        si5351_SetupPLL(SI5351_PLL_A, &pll_conf);
        pllSetupDone = true;
    }
    si5351_SetupOutput(output, SI5351_PLL_A, driveStrength, &out_conf);
}

void enableTx(bool enable) {
    HAL_GPIO_WritePin(GPIOB, GPIO_PIN_0, enable ? GPIO_PIN_SET : GPIO_PIN_RESET);
}

void changeFrequency(int32_t delta, bool force) {
    static int32_t prevFvfo = 0;

    if((!force) && lockMode) {
        return;
    }

    if(fastMode) {
        delta *= 10;
    }
    bands[currentBand].lastFreq += 100*delta;
    if(fastMode && (delta != 0)) {
        bands[currentBand].lastFreq -= bands[currentBand].lastFreq % 1000;
    }

    if(bands[currentBand].lastFreq < bands[currentBand].minFreq) {
        bands[currentBand].lastFreq = bands[currentBand].minFreq;
    } else if(bands[currentBand].lastFreq > bands[currentBand].maxFreq) {
        bands[currentBand].lastFreq = bands[currentBand].maxFreq;
    }

    // LO = IF - RF
    //if(clarMode == CLAR_MODE_RIT) {
    //    Fvfo = abs(XtalFilterCenterFrequency - (bands[currentBand].lastFreq + clarOffset));
    //} else {
    //   Fvfo = abs(XtalFilterCenterFrequency - bands[currentBand].lastFreq);
    //}

    // LO = IF + RF
    if(clarMode == CLAR_MODE_RIT) {
        Fvfo = XtalFilterCenterFrequency + (bands[currentBand].lastFreq + clarOffset);
    } else {
        Fvfo = XtalFilterCenterFrequency + bands[currentBand].lastFreq;
    }

    if(force || (Fvfo != prevFvfo)) {
        SetupCLK(CH_VFO, Fvfo, VFO_DRIVE_STRENGTH);
    }

    prevFvfo = Fvfo;
}

void displayFrequency() {
    char buff[16];
    snprintf(buff, sizeof(buff), "%02ld.%03ld.%01ld",
        bands[currentBand].lastFreq / 1000000,
        (bands[currentBand].lastFreq % 1000000) / 1000,
        (bands[currentBand].lastFreq % 1000) / 100);

    LCD_Goto(0, 0);
    LCD_SendString(buff);
}

bool buttonDitPressed() {
    return (HAL_GPIO_ReadPin(GPIOB, GPIO_PIN_12) == GPIO_PIN_RESET);
}

bool buttonDahPressed() {
    return (HAL_GPIO_ReadPin(GPIOB, GPIO_PIN_13) == GPIO_PIN_RESET);
}

void displayVccOrMode(bool force) {
    static double prevVoltage = 0.0;
    static uint32_t lastVoltageUpdateTime = 0;
    // don't forget to add '-u _printf_float' to LDFLAGS
    char buff[16];

    if(force) {
        LCD_Goto(1, 0);
        if(fastMode) {
            LCD_SendString("= FAST =");
            return;
        } else if(lockMode) {
            LCD_SendString("= LOCK =");
            return;
        } else if(clarMode != CLAR_MODE_DISABLED) {
            snprintf(buff, sizeof(buff), "%s%s%04d",
                clarMode == CLAR_MODE_RIT ? "RIT" : "XIT",
                clarOffset < 0 ? "-" : "+",
                abs(clarOffset));
            LCD_SendString(buff);
            return;
        }
    }

    uint32_t tstamp = HAL_GetTick();
    if(force || (tstamp - lastVoltageUpdateTime > 1000)) {
        double voltage = ADC_ReadVoltage(ADC_CHANNEL_2);
        voltage = voltage * 6.75;

        if(force || (abs((int)(voltage*100) - (int)(prevVoltage*100)) >= 15)) {
            // Don't re-render if we are about to transmit
            if(!buttonDitPressed() && !buttonDahPressed()) {
                if(voltage < 9.95) {
                    snprintf(buff, sizeof(buff), "VCC  %.1f", voltage);
                } else {
                    snprintf(buff, sizeof(buff), "VCC %.1f", voltage);
                }

                LCD_Goto(1, 0);
                LCD_SendString(buff);

                prevVoltage = voltage;
                lastVoltageUpdateTime = tstamp;
            }
        }
    }
}

void enterCWPlaybackOnlyMode() {
    inCWPlaybackOnlyMode = true;
}

void leaveCWPlaybackOnlyMode() {
    inCWPlaybackOnlyMode = false;
}

void keyDown() {
    if(!inCWPlaybackOnlyMode) {
        // enable keyed VCC
        HAL_GPIO_WritePin(GPIOB, GPIO_PIN_14, GPIO_PIN_SET);
    }

    // enable PWM
    // 512 is half of the Counter Period and means 50% duty cycle.
    __HAL_TIM_SET_COMPARE(&htim3, TIM_CHANNEL_4, 512);
}

void keyUp() {
    if(!inCWPlaybackOnlyMode) {
        // disable keyed VCC
        HAL_GPIO_WritePin(GPIOB, GPIO_PIN_14, GPIO_PIN_RESET);
    }

    // disable PWM
    __HAL_TIM_SET_COMPARE(&htim3, TIM_CHANNEL_4, 0);
}

void switchLPFs(UseLPF_t lpf) {
    if(lpf == USE_LPF_20_17) {
        HAL_GPIO_WritePin(GPIOA, GPIO_PIN_6, GPIO_PIN_SET); // GND_LPFS_IN
        HAL_GPIO_WritePin(GPIOA, GPIO_PIN_5, GPIO_PIN_RESET); // GND_LPFS_OUT
    } else { // lpf == USE_LPF_40_30
        HAL_GPIO_WritePin(GPIOA, GPIO_PIN_6, GPIO_PIN_RESET); // GND_LPFS_IN
        HAL_GPIO_WritePin(GPIOA, GPIO_PIN_5, GPIO_PIN_SET); // GND_LPFS_OUT
    }
}

void switchBPFs(UseBPF_t bpf) {
    HAL_GPIO_WritePin(GPIOB, GPIO_PIN_9, bpf == USE_BPF_40 ? GPIO_PIN_SET : GPIO_PIN_RESET);
    HAL_GPIO_WritePin(GPIOB, GPIO_PIN_8, bpf == USE_BPF_30 ? GPIO_PIN_SET : GPIO_PIN_RESET);
    HAL_GPIO_WritePin(GPIOB, GPIO_PIN_6, bpf == USE_BPF_20 ? GPIO_PIN_SET : GPIO_PIN_RESET);
    HAL_GPIO_WritePin(GPIOB, GPIO_PIN_7, bpf == USE_BPF_17 ? GPIO_PIN_SET : GPIO_PIN_RESET);
}

void changeBand(int32_t delta) {
    currentBand += delta;
    while(currentBand < 0) {
        currentBand += sizeof(bands)/sizeof(bands[0]);
    }
    currentBand %= sizeof(bands)/sizeof(bands[0]);

    switchBPFs(bands[currentBand].bpf);
    switchLPFs(bands[currentBand].lpf);

    changeFrequency(0, false);
    si5351_EnableOutputs(1 << CH_VFO);
    displayFrequency();
}

void ensureTransmitMode() {
    if(inTransmitMode) {
        return;
    }

    int32_t targetFrequency = bands[currentBand].lastFreq;
    if(clarMode == CLAR_MODE_XIT) {
        targetFrequency += clarOffset;
    }

    SetupCLK(CH_CW, targetFrequency, bands[currentBand].txDriveStrength);
    si5351_EnableOutputs(1 << CH_CW);

    // Switch off the BPF. Otherwhise one can hear the signal being transmitted
    // despite the fact that BFO/VFO are disabled. The signal is very quiet but the
    // frequency is a bit off the frequency of the tone generator, so the tone sounds
    // distorted.
    switchBPFs(USE_BPF_NONE);

    enableTx(true);

    LCD_Goto(1, 0);
    LCD_SendString("SWR  ---");

    inTransmitMode = true;
}

void ensureReceiveMode() {
    if(!inTransmitMode) {
        return;
    }
    enableTx(false);

    // Switch on the BPF
    switchBPFs(bands[currentBand].bpf);

    // Restore the original VFO
    changeFrequency(0, true);
    si5351_EnableOutputs(1 << CH_VFO);
    displayVccOrMode(true);
    inTransmitMode = false;
}

ButtonStatus_t buttonPressed(GPIO_TypeDef *GPIOx, uint16_t GPIO_Pin, uint32_t* lastPressed) {
    if(HAL_GPIO_ReadPin(GPIOx, GPIO_Pin) == GPIO_PIN_RESET) {
        uint32_t now = HAL_GetTick();
        if(now - *lastPressed > BUTTON_DEBOUNCE_TIME_MS) {
            *lastPressed = now;
            return BUTTON_STATUS_PRESSED;
        } else {
            return BUTTON_STATUS_DEBOUNCE;
        }
    }
    return BUTTON_STATUS_RELEASED;
}

ButtonStatus_t buttonNextPressed() {
    static uint32_t lastPressed = 0;
    return buttonPressed(GPIOC, GPIO_PIN_15, &lastPressed);
}

ButtonStatus_t buttonFastPressed() {
    static uint32_t lastPressed = 0;
    return buttonPressed(GPIOC, GPIO_PIN_14, &lastPressed);
}

ButtonStatus_t buttonLockPressed() {
    static uint32_t lastPressed = 0;
    return buttonPressed(GPIOB, GPIO_PIN_15, &lastPressed);
}

ButtonStatus_t buttonClarPressed() {
    static uint32_t lastPressed = 0;
    return buttonPressed(GPIOB, GPIO_PIN_4, &lastPressed);
}

ButtonStatus_t buttonKeyerPressed() {
    static uint32_t lastPressed = 0;
    return buttonPressed(GPIOA, GPIO_PIN_7, &lastPressed);
}

// `straightKeyerKeyIsDown` is used to avoid calling keyUp()/keyDown() if we did it already.
// Calling HAL_GPIO_WritePin() too often generates a hearable noise.
bool straightKeyerKeyIsDown;

void initStraightKeyer() {
    straightKeyerKeyIsDown = false;
}

void processStraightKeyerLogic(bool pressed) {
    if(pressed) {
        if(!straightKeyerKeyIsDown) {
            keyDown();
            straightKeyerKeyIsDown = true;
        }
    } else if(straightKeyerKeyIsDown) {
        keyUp();
        straightKeyerKeyIsDown = false;
    }
}

void initIambicKeyer() {
    // iambic keyer has nothing to init
}

static size_t iambicKeyerLogOffset = 0;
static char iambicKeyerLog[MAX_KEYER_MESSAGE_LENGTH] = {0};

void iambicKeyerLogReset() {
    iambicKeyerLogOffset = 0;
}

size_t iambicKeyerLogSize() {
    return iambicKeyerLogOffset;
}

size_t iambicKeyerLogSpaceLeft() {
    return MAX_KEYER_MESSAGE_LENGTH - iambicKeyerLogOffset;
}

// Iambic keyer logs up to MAX_KEYER_MESSAGE_LENGTH symbols.
// '.' is a dit
// '-' is a dah
// ' ' is a pause between letters
// '/' is a pause between words
// Multiple pauses between letters are logged as one pause.
// Multiple pauses between words are also logged as one pause.
// Pauses in the beginning of the message are not logged.
void iambicKeyerLogEmit(char c) {
    if(iambicKeyerLogSpaceLeft() == 0) {
        // truncate the message if there is not space left in the buffer
        return;
    }

    if(((c == ' ') || (c == '/')) && (iambicKeyerLogOffset == 0)) {
        // don't log the pauses in the beginning of the message
        return;
    }

    if((c == ' ') && iambicKeyerLog[iambicKeyerLogOffset-1] == ' ') {
        // multiple pauses between letters are logged as one pause
        return;
    }

    if((c == '/') && iambicKeyerLog[iambicKeyerLogOffset-1] == '/') {
        // multiple pauses between words are logged as one pause.
        return;
    }

    if((c == '/') && iambicKeyerLog[iambicKeyerLogOffset-1] == ' ') {
        // previously logged pause between letters became a pause between words
        iambicKeyerLog[iambicKeyerLogOffset-1] = '/';
        return;
    }

    if((c == ' ') && iambicKeyerLog[iambicKeyerLogOffset-1] == '/') {
        // to my knowledge this should never happen...
        return;
    }

    // log the symbol
    iambicKeyerLog[iambicKeyerLogOffset] = c;
    iambicKeyerLogOffset++;
}

void processIambicKeyerLogic(bool ditPressed, bool dahPressed) {
    static int32_t sendFinish = 0;
    static int32_t keyReadTimeout = 0;
    static int32_t sendTimeout = 0;
    static bool isSending = false;

    int32_t now = HAL_GetTick();

    if(isSending && (now >= sendFinish)) {
        keyUp();
        isSending = false;
    } else if(!isSending && (now - sendFinish) > keyerConfig.ditTimeMs*5) {
        // multiple pauses between words will be logged as one pause
        // pauses in the beginning of the message will be ignored
        iambicKeyerLogEmit('/');
    } else if(!isSending && (now - sendFinish) > keyerConfig.ditTimeMs*2) {
        // multiple pauses between letters will be logged as one pause
        // pauses in the beginning of the message will be ignored
        iambicKeyerLogEmit(' ');
    }

    if(nextSend == CW_SEND_NONE) {
        if(ditPressed && (lastSent == CW_SEND_DAH)) {
            nextSend = CW_SEND_DIT;
        } else if(dahPressed && (lastSent == CW_SEND_DIT)) {
            nextSend = CW_SEND_DAH;
        } else if(now > keyReadTimeout) {
            if(ditPressed) {
                nextSend = CW_SEND_DIT;
            } else if (dahPressed) {
                nextSend = CW_SEND_DAH;
            }
        }
    }

    if((now > sendTimeout) && (nextSend != CW_SEND_NONE)) {
        if(nextSend == CW_SEND_DIT) {
            iambicKeyerLogEmit('.');
            sendFinish = now + keyerConfig.ditTimeMs;
            keyReadTimeout = now + keyerConfig.ditTimeMs*2;
        } else if(nextSend == CW_SEND_DAH) {
            iambicKeyerLogEmit('-');
            sendFinish = now + keyerConfig.ditTimeMs*3;
            keyReadTimeout = now + keyerConfig.ditTimeMs*3;
        }

        lastSent = nextSend;
        nextSend = CW_SEND_NONE;
        sendTimeout = sendFinish + keyerConfig.ditTimeMs;
        isSending = true;
        keyDown();
    }
}
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
int main(void)
{
  /* MCU Configuration--------------------------------------------------------*/

  /* Reset of all peripherals, Initializes the Flash interface and the Systick. */
  HAL_Init();

  /* Configure the system clock */
  SystemClock_Config();

  /* Initialize all configured peripherals */
  MX_GPIO_Init();
  MX_ADC1_Init();
  MX_I2C2_Init();
  MX_TIM1_Init();
  MX_TIM2_Init();
  MX_TIM3_Init();
  /* USER CODE BEGIN 2 */
  init();
  /* USER CODE END 2 */

  /* Infinite loop */
  /* USER CODE BEGIN WHILE */
  while (1)
  {
    loopMain();
    /* USER CODE END WHILE */

    /* USER CODE BEGIN 3 */

  }
  /* USER CODE END 3 */
}

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


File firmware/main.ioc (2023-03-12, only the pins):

Mcu.UserName=STM32F103C8Tx
PA0-WKUP.Signal=ADCx_IN0
PA1.Signal=ADCx_IN1
PA13.Signal=SYS_JTMS-SWDIO
PA14.Signal=SYS_JTCK-SWCLK
PA15.Signal=S_TIM2_CH1_ETR
PA2.Signal=ADCx_IN2
PA5.Signal=GPIO_Output
PA6.Signal=GPIO_Output
PA7.Signal=GPIO_Input
PA8.Signal=S_TIM1_CH1
PA9.Signal=S_TIM1_CH2
PB0.Signal=GPIO_Output
PB1.Signal=S_TIM3_CH4
PB10.Signal=I2C2_SCL
PB11.Signal=I2C2_SDA
PB12.Signal=GPIO_Input
PB13.Signal=GPIO_Input
PB14.Signal=GPIO_Output
PB15.Signal=GPIO_Input
PB3.Signal=S_TIM2_CH2
PB4.Signal=GPIO_Input
PB6.Signal=GPIO_Output
PB7.Signal=GPIO_Output
PB8.Signal=GPIO_Output
PB9.Signal=GPIO_Output
PC13-TAMPER-RTC.Signal=GPIO_Output
PC14-OSC32_IN.Signal=GPIO_Input
PC15-OSC32_OUT.Signal=GPIO_Input
PD0-OSC_IN.Signal=RCC_OSC_IN
PD1-OSC_OUT.Signal=RCC_OSC_OUT

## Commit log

2023-03-12 Move project from a sandbox repository
    [BOM.csv, af-amplifier.sch, analog-bfo.sch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]
2023-03-12 Copy stl-files/ from AYN/DC project
    [desktop-stand.scad, desktop-stand.stl, dust-cover.scad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]

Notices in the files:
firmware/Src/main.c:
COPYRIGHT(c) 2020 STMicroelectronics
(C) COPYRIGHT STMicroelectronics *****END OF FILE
